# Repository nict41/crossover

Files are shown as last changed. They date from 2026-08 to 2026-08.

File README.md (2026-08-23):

# Variable Crossover — ESP Project 148

An EasyEDA-importable schematic for the **3-way state variable electronic
crossover** from Elliott Sound Products Project 148
(<https://sound-au.com/project148.htm>), redrawn from Figure 2.

Two cascaded 2nd-order state variable filters, 12 dB/octave, with continuously
variable crossover frequencies and adjustable Q. One channel — build two for
stereo.

Four variants are provided. They are the **same circuit** — identical filter
topology and identical signal connectivity, which the generator asserts on
every build — differing in the components that set the frequency range, in
whether the eight op-amp sections are packaged as four duals or two quads,
and in whether the board extras (volume controls, buffered outputs, muting)
are drawn:

| Variant | High/Mid | Mid/Low | Op-amps | File |
|---|---|---|---|---|
| Stock ESP P148 | 680 Hz – 4.8 kHz | 68 – 480 Hz | 4 × NE5532 dual | `esp-p148-3way-state-variable-crossover.json` |
| Retuned | 195 Hz – 1.03 kHz | 71 – 180 Hz | 4 × NE5532 dual | `esp-p148-3way-crossover-retuned-200hz-1khz.json` |
| Retuned, quad | 195 Hz – 1.03 kHz | 71 – 180 Hz | 2 × MC33079 quad | `esp-p148-3way-crossover-retuned-quad.json` |
| Retuned, quad, **SMD** | 195 Hz – 1.03 kHz | 73 – 186 Hz | 3 × MC33079 SOIC-14 | `esp-p148-3way-crossover-retuned-quad-smd.json` |

The **Retuned, quad** variant is electrically identical to the retuned one —
it just packs the same eight sections into two 14-pin quads instead of four
duals, which also halves the bypass caps (8 → 4). One quad per filter, so the
sections sharing a package are the ones already coupled by design.

The **SMD** variant is the one in `pcb/`, and it is not only a repackaging:
it adds a third quad (`U3`) for the output buffers, plus the volume controls,
the muting and the output DC blocking. That is why it lists three MC33079
where the through-hole quad variant lists two.

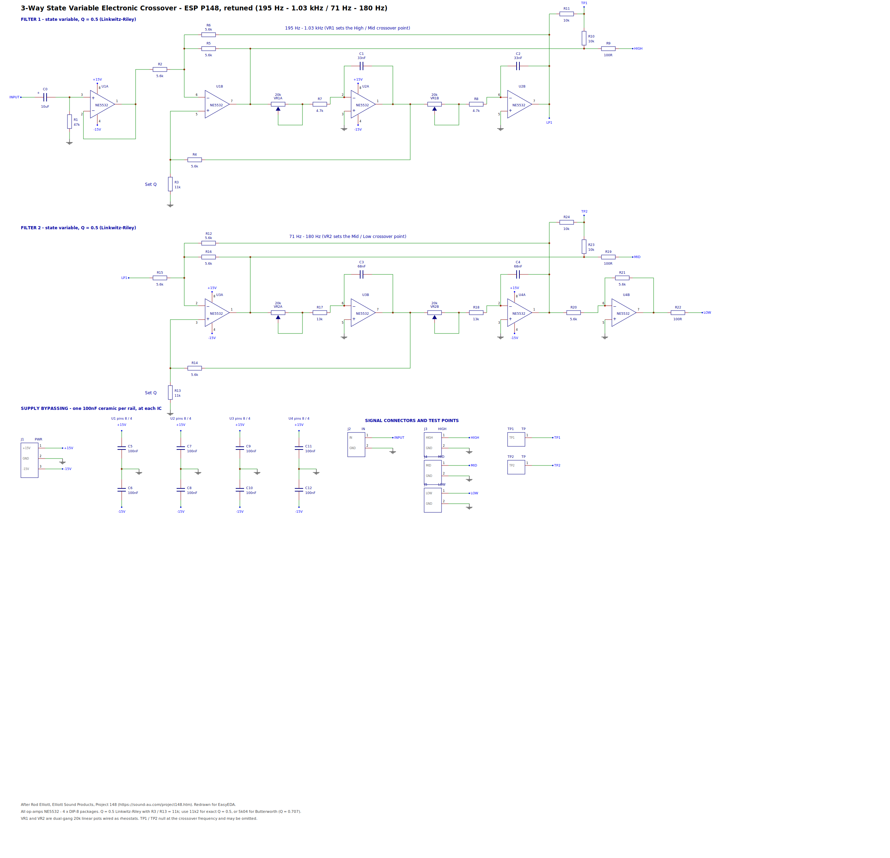
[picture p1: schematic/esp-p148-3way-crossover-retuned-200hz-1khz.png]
Schematic preview


## Importing into EasyEDA

Everything here targets **EasyEDA Standard** (<https://easyeda.com/editor>) —
the generated JSON is Std's `docType: 3` PCB / `docType: 1` schematic format.
EasyEDA Pro can read it via **File → Import → EasyEDA Std**.

### The PCB (the finished, routed board)

1. Open <https://easyeda.com/editor> and go to **File → Open → EasyEDA…**
2. Choose `pcb/esp-p148-3way-crossover-retuned-quad-smd-pcb.json`.

It opens as a complete **four-layer** board: routed, with a solid ground
plane on Inner1 and a ground pour on the other three, and real LCSC part
numbers already attached to every assembled component. Nothing needs
assigning before you can look at it or order it — but do rebuild the copper
areas first, for the reason in the next section.

### The schematic

Same menu, then a `.json` from `schematic/` — one per variant. If your
editor build rejects it, try the matching `.legacy.json`: identical
drawing, older string-form document header.

Schematic symbols carry **generic** package names (`R_AXIAL-0.4`, `DIP-8`,
…), so the schematic on its own is not ready for layout — but you do not
need it to be, because the PCB above is already laid out. The two are
separate documents rather than one linked project, so EasyEDA will not
cross-check them; `gen_pcb_smd.py` does that instead, and asserts the
board's pads match the schematic's pins exactly on every run.

### What to check once it is open

The generator verifies its own geometry and `tools/validate_fab.py` checks
the file against EasyEDA's format and JLCPCB's limits, but a few things can
only be confirmed by a real import:

1. **Rebuild the copper areas** (right-click a pour → *Rebuild copper
   area*, or **Tools → Rebuild all copper areas**). Ground is a **plane**
   on this board, not a routed net — Inner1 is a solid ground plane, the
   other three layers are poured, and only
   a handful of short stubs are drawn as traces. This used to be optional
   insurance; it is now the thing that connects ground, so do it before
   the DRC below or the DRC will tell you ground is unconnected.
2. **Does the silkscreen appear?** This is the one known unknown. Our
   `TEXT` shapes are written without the pre-rendered glyph path that
   EasyEDA's own exports carry, relying on the editor to re-render from the
   text and size. Normal for generated files, expected to work, unverified
   here. If the designators and pin labels are missing, that is why.
3. **Design → Design Rule Check**, with JLCPCB's rule set. It should be
   clean; the repo's own checker already requires ≥ 8 mil clearance against
   JLCPCB's 5 mil limit.
4. **Look at the 3D view / photo view.** Part orientation is the usual
   failure mode for a hand-drawn footprint, and the SOIC-14's pin-1
   rotation against JLCPCB's convention is explicitly unconfirmed (see
   "Known limitations").
5. **Export Gerbers, BOM and CPL from EasyEDA**, not from this repo — see
   "Ordering" in `docs/pcb-notes-smd.md` for why the CPL here is reference
   only.

## Before you build this

Read [`docs/design-review.md`](docs/design-review.md). It lists the failure
modes that pass every automated check, marks which of them the board now
fixes, and keeps the reasoning for the ones it does — including why turn-on
transients from an active crossover are a tweeter problem specifically
(fixed: JFET muting with soft start), and why per-band volume knobs with no
master is the wrong control architecture for a preamp (fixed: `VR6`). What
is left is mostly mechanical: unverified hand-drawn footprints, and the
fact that nothing here has been built and measured.

## Repository layout

```
schematic/   EasyEDA schematics (.json + .legacy.json), one pair per variant,
             each with a matching .svg / .png preview
pcb/         the routed SMD board (+ .svg / .png preview)
docs/        circuit-notes.md      — how the circuit works, design equations
             pcb-notes-smd.md      — the board: layout, routing, verification
             design-review.md      — what could still go wrong
             panel-drilling.md     — GENERATED: front-panel hole positions
             parts.md              — GENERATED: the BOM, plus what you solder
             task-board.md         — open work, and what serialises
             decisions.md          — append-only log of what was measured
             subcircuits/          — GENERATED: one diagram per function block
             crossover-ranges.svg  — tuning-range diagram (+ .png)
             netlist.txt           — netlist extracted back out of the drawing
bom/         one bom-*.csv per variant, plus the JLCPCB BOM and CPL
tools/       gen_schematic.py     — generates the schematics
             gen_pcb_smd.py       — SMD PCB, routed + verified
             gen_range_diagram.py — generates the range diagram
             validate_fab.py      — EasyEDA import + JLCPCB limit checks
             find_board.py        — searches seeds/route orders for a clean board
             gen_spice.py         — SPICE deck, from the same netlist as the board
             run_sim.py           — runs the circuit-verification suite
             place.py / anneal.c / canneal.py   — the placement anneal
             router.c / croute.py               — the grid maze router
             geom.c  / cgeom.py                 — the exact-geometry checks
sim/         GENERATED: the ngspice deck (crossover.net, models.lib,
             jfet-*.lib). Analysis decks and their results are not committed.
```

`place.py`, `router.c` and `geom.c` each have a Python reference
implementation beside the compiled one (`PLACER=py`, `ROUTER=py`,
`CGEOM=py`), so every compiled path can be checked against readable code.

## Contributing (human or agent)

[`AGENTS.md`](AGENTS.md) is the one-page contract — it matters here more
than in most repositories, because almost everything in `schematic/`,
`pcb/`, `bom/`, `sim/` and several files in `docs/` is **generated**, and
editing the output instead of the generator is silently discarded.

```sh
python3 tools/check_all.py     # the gate: regenerate, verify, validate
```

Open work is in [`docs/task-board.md`](docs/task-board.md), marked by
whether it forces a board re-search (and so can only be done one at a
time). Measurements — kept *and* rejected — go in
[`docs/decisions.md`](docs/decisions.md).

## Regenerating

The schematic is generated, not hand-edited, so that the drawing and the netlist
can't drift apart:

```sh
python3 tools/gen_schematic.py      # schematics, previews, netlists, BOMs
python3 tools/gen_pcb_smd.py        # SMD board (routed; needs numpy)
python3 tools/gen_range_diagram.py  # docs/crossover-ranges.svg + .png
python3 tools/validate_fab.py --online   # EasyEDA import + JLCPCB limits
python3 tools/gen_spice.py && python3 tools/run_sim.py   # circuit simulation
```

`gen_spice.py` builds the ngspice deck from the **same netlist JSON the
board is built from**, so the thing that gets simulated cannot drift from
the thing that gets manufactured. `run_sim.py` then measures the crossover
points, the summed response, the DC at each output terminal, and the mute
chain. It needs `ngspice` (`apt install ngspice`).

`gen_pcb_smd.py` reads the netlist JSON that `gen_schematic.py` writes, so the
board cannot drift from the schematic — run them in that order.

Both need `cairosvg` for PNG output (`pip install cairosvg`); the SVGs are
written regardless.

The script places every component and wire on a 10 px grid, derives junction
dots from wire degree, then **re-extracts the netlist from the finished
geometry** and prints it. That extracted netlist is what's in `docs/netlist.txt`
— it is a check on the drawing, not a restatement of intent.

It builds every entry in `VARIANTS` and asserts that they all produce the same
netlist, so a retune that accidentally changed a connection would fail the
build rather than ship quietly.

## Circuit summary

Designators below are the **four-dual** drawing's. On the quad variants —
including the board — the same eight sections are U1A–D and U2A–D; that
mapping, and every part the board adds beyond the filter, is in
[`docs/circuit-notes.md`](docs/circuit-notes.md#function-blocks-on-the-smd-board).

| | Filter 1 | Filter 2 |
|---|---|---|
| Summing amp (high-pass out) | U1B → **HIGH** | U3A → **MID** |
| Integrator 1 (bandpass, feedback only) | U2A | U3B |
| Integrator 2 (low-pass out) | U2B → filter 2 | U4A → U4B → **LOW** |
| Frequency pot | VR1 (dual 20k) | VR2 (dual 20k) |
| Integrator caps | C1, C2 | C3, C4 |
| Q resistor | R3 = 12k | R13 = 12k |

Q = (5.6k + Rq) / (3 × Rq): 11k2 gives exactly 0.5 (Linkwitz-Riley), 11k gives
0.503, 12k gives 0.489, 5k04 gives Butterworth (Q = 0.707, 3 dB peak in the
summed response). The stock variant keeps the published 12k; the retuned
variant uses 11k, which is a stock value and four times closer to ideal.

The inverter U4B sits on the **bass** output rather than the midrange because
U3A, the input amplifier of the second filter, is already inverting.

TP1 and TP2 sum each filter's high-pass and low-pass outputs through 10 k
resistors; the signal nulls at the crossover frequency, so you can measure it
exactly with an oscillator. They're optional — the ESP PCB omits them.

### Tuning ranges

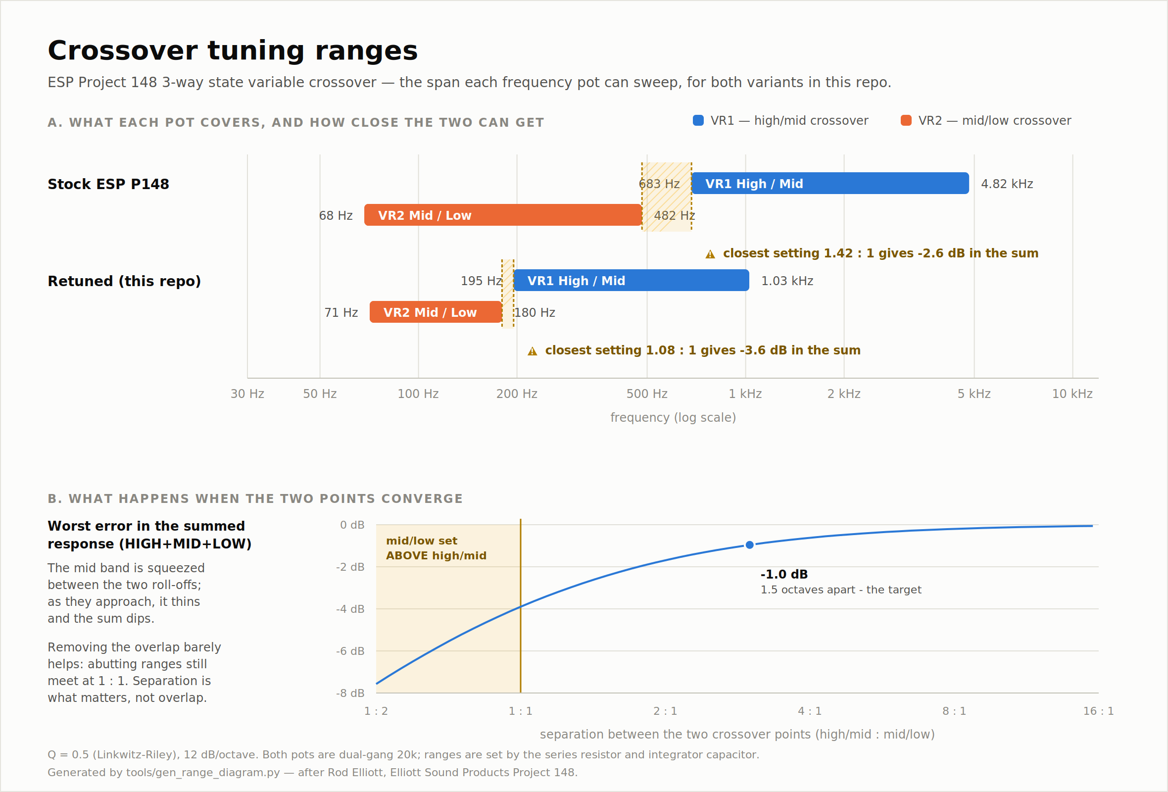
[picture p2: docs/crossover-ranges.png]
Crossover tuning ranges


The retuned ranges don't overlap, but that is **not** what keeps the response
flat — separation is. Because the two filters are tuned independently, nothing
stops you setting them close together, and ranges that merely abut still meet
at the boundary:

| Range layout | Closest possible setting | Sum error there |
|---|---|---|
| Stock ESP P148 | 1.42 : 1 | −2.62 dB |
| Retuned | 1.08 : 1 | −3.57 dB |

The outputs never swap — filter 1 is unaware of filter 2, so HIGH is
unaffected. What collapses is MID, whose passband *is* the gap between the two
corners: squeeze that gap and it thins out, and the summed response develops a
broad suck-out. The degradation is gradual and already measurable at 1.6 : 1,
so the rule is **keep the two points at least 3 : 1 apart** (~1.5 octaves) for
under 1 dB. That's setting discipline, not something the hardware enforces —
note the stock ESP values have the same exposure. Nothing is damaged or
unstable; turn VR2 back down and it recovers. Full detail in
[`docs/circuit-notes.md`](docs/circuit-notes.md#setting-the-two-points-too-close-together).

### Frequency range

`f = 1/(2πRC)`, where R sweeps from the series resistor alone to series + 20 k
pot. The series resistor therefore sets both the top frequency *and* the
max/min ratio:

| Variant | R7, R8 | C1, C2 | High/Mid | R17, R18 | C3, C4 | Mid/Low |
|---|---|---|---|---|---|---|
| Stock | 3.3k | 10 nF | 683 Hz – 4.82 kHz | 3.3k | 100 nF | 68.3 – 482 Hz |
| Retuned | 4.7k | 33 nF | 195 Hz – 1.03 kHz | 13k | 68 nF | 70.9 – 180 Hz |

Nothing else differs — same Q, same op-amps, same 20 k pots. Larger series
resistors also load the previous stage *less*, so this direction is safe; the
article only warns against going below ~2.2k.

Full explanation, design equations and frequency tables: [`docs/circuit-notes.md`](docs/circuit-notes.md).

## Subcircuits

One diagram per functional block of the board, in
**[docs/subcircuits/](docs/subcircuits/README.md)**: input and master volume,
each of the two crossover filters, the level controls, the output buffers, the
two halves of the muting circuit, and power/decoupling.

They are **generated, not drawn**. `tools/gen_schematic.py` crops each block
out of the full sheet through the same `render_svg()` that renders the main
schematic, so the symbols, strokes and fonts are identical to it and cannot
drift. Rebuild them with:

```bash
python3 tools/gen_schematic.py
```

The part-by-part tables that go with the pictures are in
[docs/circuit-notes.md](docs/circuit-notes.md#function-blocks-on-the-smd-board).

## Additions to the original drawing

The ESP figures deliberately leave out supply wiring. This schematic adds it so
the netlist is complete:

* **J1** — ±15 V and ground input.
* **C5–C10** — 100 nF ceramic from each op-amp package's positive and negative
  supply pin to ground, as the article's text requires. Mount them right at
  the ICs; the board's placement search prices the distance directly.
* **C11, C12** — 10 µF bulk reservoir, one per rail.
* **R10/R11** and **R23/R24** — the unlabelled 10 k test-point resistors in
  Figure 2, given designators.

The `retuned-quad-smd` variant — the one the board is built from — adds more
still: a master volume, per-band volume trims, buffered outputs with DC
blocking and bleeders, and per-output muting with soft start. Every part and
what it does is listed in
[`docs/circuit-notes.md`](docs/circuit-notes.md#function-blocks-on-the-smd-board).

## Known limitations

### Of the schematics

These apply to the four `schematic/` variants. **None of them applies to the
routed board** — it has real footprints, real LCSC part numbers and a
verified layout; see the next list for its limitations.

* **Op-amps are drawn as separate sections** (U1A/U1B, U2A/U2B, …) rather than
  as multi-part components, so the BOM lists eight NE5532s where you only need
  four dual packages. Before PCB layout, merge each pair onto one DIP-8/SOIC-8
  part in EasyEDA. Supply pins 8 and 4 appear on the A section of each package
  only, which is the usual convention.
* **VR1 and VR2 are two dual-gang 20 k pots**, drawn as four gangs (VR1A, VR1B,
  VR2A, VR2B). Both gangs of a pot must track reasonably well.
* **VR3–VR6 are single-gang audio-taper pots** — three band trims and a
  master. They are passive attenuators, not part of any filter.
* **Footprints are placeholders** in the schematics. Assign real ones from the
  EasyEDA/LCSC library for your parts (axial vs. 0805, pot body, etc.).
* One deliberate wire crossing per filter, where the low-pass feedback rail
  crosses the high-pass rail. Crossings without a junction dot do not connect.

### Of the routed board

* **Nothing here has been built or measured.** It is verified against its own
  netlist, its own geometry, and — since the simulation work — its own
  behaviour in ngspice. All three are different claims from "it works on a
  bench".
* **The simulation cannot predict THD.** The op-amp is a behavioural
  macromodel with no device-level nonlinearity, so the distortion floor it
  reports is a measurement artefact. It is good for topology questions —
  does a device conduct when it should not, where do the crossover points
  land, what DC reaches the output — and useless for a distortion figure.
* **Winding both frequency knobs together collapses the mid band.** The
  two ranges deliberately do not overlap (73–186 Hz and 195 Hz–1.03 kHz),
  but they are *adjacent*: set both to the near end and the mid band is
  9 Hz wide, peaks 11.7 dB down, and the summed response has a 3.6 dB
  hole. Nothing prevents it and nothing on the panel warns about it —
  keep the two knobs apart.
* **Three footprints are hand-drawn and unconfirmed against a datasheet** —
  SOIC-14, the 10 µF electrolytic, and the dual-gang pot body. The pot's
  locating-boss holes are absent rather than guessed: a hole in the wrong
  place is a re-order, a missing one is a hand drill.
* **Whether the silkscreen renders after import is untested.** Our `TEXT`
  shapes carry no pre-rendered glyph path, which is normal for generated
  files and expected to work — but it is the one thing that cannot be
  checked without importing.
* **The board is past JLCPCB's 100 × 100 mm price tier** at 149.6 mm on its
  long side. That is set by the nine front-panel controls, not by routing:
  a control costs panel width whatever the router does.

## KiCad

`kicad/esp-p148-3way-crossover-retuned-quad-smd.kicad_sch` — the same
schematic as a **KiCad 8 schematic**, generated by `tools/gen_kicad.py`.
Open `kicad/crossover.kicad_pro`, or the `.kicad_sch` on its own.

It is **self-contained**: every symbol is embedded in the file's own
`lib_symbols`, one per component instance, so nothing needs to be
installed and no library path has to resolve. Nets are carried by labels
exactly as they are drawn.

It is not a second drawing of the circuit. `gen_kicad.py` reads the very
geometry `gen_schematic.py` lays out — every pin in absolute coordinates,
every wire polyline, every label — and translates it, so the two cannot
disagree about connectivity. And it checks: after emitting the file it
parses it back, rebuilds the netlist from the geometry alone, and refuses
to write anything unless that matches the schematic's own netlist.

`kicad/esp-p148-3way-crossover-retuned-quad-smd.kicad_pcb` — a **routing
seed**, for handing to an external router or placement tool. It is placed
but not wired:

* the committed outline at its real size, **149.6 × 63.5 mm**;
* the **edge components on the board** at their committed positions — the
  nine front-panel controls and the five rear connectors — because those
  are mechanical and not a router's to move;
* **every other part parked outside the outline** on a grid, to be placed;
* the full netlist on the pads, so there is a ratsnest to work from;
* the four mounting holes, so nothing routes through a screw;
* and **no tracks, no vias and no zones** — not even the ground pour this
  project otherwise treats as load-bearing.

It is read from the committed `pcb/*.json`, so it cannot describe a board
that was never built, and the emitted file is parsed back and checked
before it is written: bare of copper, every edge part inside the outline,
every other part clear of it, pad nets identical to the board's.

## PCB

### SMD board, routed, for JLCPCB fab + assembly

`pcb/esp-p148-3way-crossover-retuned-quad-smd-pcb.json` — **149.6 ×
63.5 mm**, **four layers**, **fully routed**, nine front-panel controls on
the board (a frequency pot and a volume trim per band, a master volume, and
a mute button per band), trace width matched to purpose (12 mil signal,
16 mil power/ground), 45° chamfered corners, every SMD part a real LCSC
line item.

The stackup is L1 signal / **L2 solid GND plane** / L3 signal / L4 signal.
Two layers could not route this board once the three panel mute buttons
went into the front row — see
[`docs/pcb-notes-smd.md`](docs/pcb-notes-smd.md#the-stackup).

Every part that reaches an edge is pinned into one of two rows — the panel
row on the front, the connector row on the back — and nothing may sit
outside either, so the board edges land 1.27 mm behind them. See
[Two pinned edge rows](docs/pcb-notes-smd.md#two-pinned-edge-rows).

Every SMD ground pad is **fanned out to the plane before any signal net is
routed** — a via on the pad, straight down. Repairing ground afterwards
does not work once the traces are down, and that is what used to leave
op-amp ground pins stranded.

Beyond the filter itself it carries buffered outputs with build-out
resistors, DC blocking and bleeders, a 47 kΩ line input, bulk and per-IC
supply decoupling, and **per-output muting with power-up soft start** — a
JFET shunting each buffer input, steering diodes so one button mutes one
band, and an RC that holds everything muted until the rails settle and
re-mutes fast when they collapse. The three mute buttons are **on the
board**, in the panel row beside the volume trims - right-angle push-lock
DPDTs, so their plungers come out of the board edge alongside the pot
shafts. `J6` carries only the optional panel LEDs, which light when a band
is playing. No audio leaves the board. Which parts do what, block
by block, is in
[`docs/circuit-notes.md`](docs/circuit-notes.md#function-blocks-on-the-smd-board).

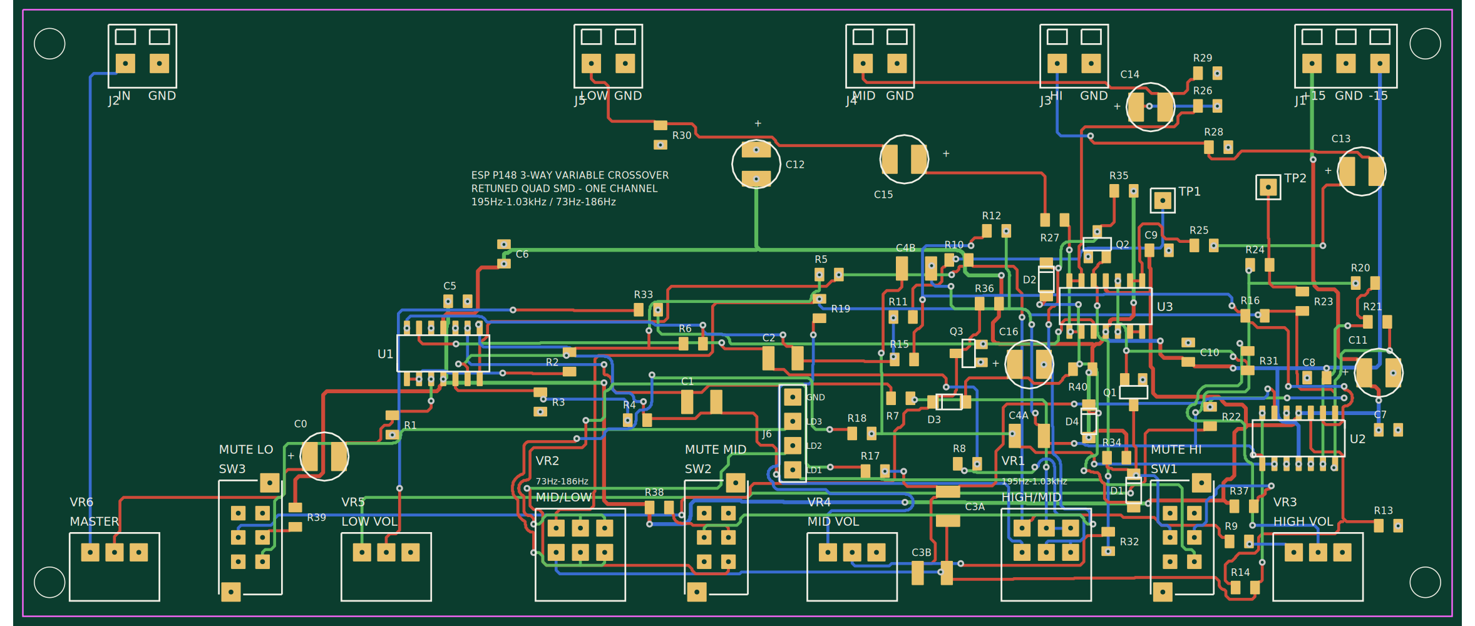
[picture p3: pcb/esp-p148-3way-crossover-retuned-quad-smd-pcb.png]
SMD board


```
board 149.6 x 63.5 mm | 86 footprints | 242 pads | 227 tracks | 159 vias
verified: all nets connected, all clearances >= 8 mil, no unrouted nets,
          pads match the schematic exactly
```

On the rear edge, left to right: **line input, LOW, MID, HIGH, power** —
the three outputs adjacent and in the same order as the front panel, with
the power block at the far end from the input so the two looms never run
together. On the front edge, left to right: MASTER,
**LOW mute**, LOW volume, MID/LOW frequency, **MID mute**, MID volume,
HIGH/MID frequency, **HIGH mute**, HIGH volume — nine controls, each mute
button beside the volume trim it mutes. The board lies **flat in the
enclosure, perpendicular to the front panel**, with right-angle pots and
right-angle switches on the front edge and their shafts and plungers
through the panel — the way a small amplifier board is usually arranged.
The frequency pots carry their sweep range on the silkscreen. The volume controls are single-gang
audio-taper pots (Alps RK097 pattern) wired as attenuators; the frequency
pots are the standard 9 mm dual-gang pattern. Both **need checking against
your parts' datasheets** — there are no locating-boss holes, deliberately;
see the notes.

**Drilling the panel:** [`docs/panel-drilling.md`](docs/panel-drilling.md)
is generated from the same placement as the copper, and gives the X of every
shaft and plunger from the board's left edge, the two pitches the row uses,
and where the four mounting holes actually ended up. Regenerate the board
and that file follows it, so it cannot drift from the part positions the way
a measured-off-the-preview drawing would.

Routing is checked by geometry that doesn't reuse the router's own bookkeeping:
exact pairwise clearance between every copper feature, union-find connectivity
per net, mounting-hole keepout, footprint-courtyard overlap, and pad-set
equality with the schematic. Those checks have caught real defects that would
otherwise have reached the fab, including a pre-existing footprint overlap
between two adjacent parts that nothing before the courtyard check could even
detect — see [`docs/pcb-notes-smd.md`](docs/pcb-notes-smd.md).

Part numbers were looked up live against the JLCPCB parts API; **re-check stock
before ordering**. Export Gerbers, BOM *and* CPL from EasyEDA rather than using
the CPL in this repo — a CPL's origin has to match the Gerbers, and only EasyEDA
knows that at export time.

JLCPCB won't assemble through-hole parts. **69 of the 86 footprints are
machine-placed**; the 17 you solder yourself are all through-hole and all of
them are edge or panel hardware:

* `VR1`–`VR6` — the six pots
* `SW1`–`SW3` — the three mute buttons
* `J1`–`J5` — power in, line in, and the three outputs
* `J6` — the optional panel-LED header
* `TP1`, `TP2` — the two test points

There is no off-board pot or switch wiring any more: every control is an
edge-mount part on the board itself.

## Getting the most out of it

The circuit is already lean, so build effort is easy to spend in the wrong
place. In order of what actually measures:

1. **Match within each filter.** The two integrator caps (C1/C2, C3/C4) and the
   two series resistors need to match *each other* — absolute value only sets
   the range. A mismatch acts exactly like pot mistracking, moving f0 and Q by
   its square root: 10 % costs −0.41 dB, 20 % costs −0.79 dB. Use 1 % resistors
   and matched caps; 5 % is fine everywhere else.
2. **Buy pot tracking, not exotic op-amps.** Same maths applies to the two
   gangs. And don't fit log-taper pots for a more even frequency scale — their
   gang tracking is much worse, and it lands straight on Q.
3. **Q resistor 11k, not 12k** — already done in the retuned variant. Free.
4. **Two quads instead of four duals** — shipped as the `retuned-quad`
   variant. The circuit splits perfectly at the filter boundary, four sections
   each, so one quad per filter: half the ICs, half the bypass caps, smaller
   board, no circuit change. Drawn with the MC33079 (closest in character to
   the NE5532); any standard quad pinout drops in — OPA1644, OPA4134,
   LME49740, TL074.

Things that look like simplifications but aren't: the input buffer U1A keeps
source impedance out of the Q and gain; the integrators have no DC feedback of
their own, so the state-variable loop must stay intact. Detail in
[`docs/circuit-notes.md`](docs/circuit-notes.md#where-accuracy-actually-pays).

## Building notes

* NE5532 is what the article specifies, for noise. Any decent audio dual op-amp
  will work.
* The 5.6 k resistors were 10 k in earlier versions of the article; 5.6 k was
  chosen to reduce thermal noise. Anything up to 10 k is fine, above that isn't
  recommended.
* To move a frequency range, change the integrator capacitors — smaller caps
  give a higher range. 4.7 nF in filter 1 gives roughly 1.45 kHz – 10 kHz.
  Watch that a test tweeter isn't driven below its rated minimum frequency.

## Credit and licence

Circuit design © Rod Elliott, Elliott Sound Products, Project 148 (2014).
The ESP article grants personal use and one printed copy for reference while
building; commercial use needs Rod Elliott's written permission. This repository
holds a re-drawn schematic for personal construction — please read the article
itself, and buy the ESP PCB if you want one.

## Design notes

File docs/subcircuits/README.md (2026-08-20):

# Subcircuit diagrams

One diagram per functional block of the SMD board. They are **generated**,
not drawn: `tools/gen_schematic.py` crops each block out of the full sheet
through the same `render_svg()` the main schematic uses, so the symbols,
strokes and fonts are identical and cannot drift from it. Re-run
`python3 tools/gen_schematic.py` to rebuild them.

The part-by-part tables for each block are in
[`../circuit-notes.md`](../circuit-notes.md#function-blocks-on-the-smd-board);
these are the pictures.

## Input and master volume

The line input, the master volume ahead of everything, and the unity-gain buffer that drives the first filter.

Input and master volume

## Crossover filter 1 - the HIGH / MID split

State-variable filter. `U1B`'s output IS the high-pass; `U1D`'s is the low-pass that feeds filter 2. `VR1` sets the split frequency.

Crossover filter 1 - the HIGH / MID split

## Crossover filter 2 - the MID / LOW split

The same topology again on filter 1's low-pass output, splitting it into MID and LOW. `U2D` inverts the bass output.

Crossover filter 2 - the MID / LOW split

## Level controls

Master volume plus one trim per band, all passive attenuators after the filter and before the buffer.

Level controls

## Output buffers and DC blocking

One unity-gain buffer per band, a build-out resistor, a DC blocking cap and a bleeder, into a terminal block with its own ground return.

Output buffers and DC blocking

## Muting - the shunt devices in the signal path

`Q1`-`Q3` shunt each buffer input to ground through `R31`-`R33`. Drawn here rather than with the rest of the mute circuit because this is where they sit electrically: across the buffer input.

Muting - the shunt devices in the signal path

## Muting - gate control, buttons and soft start

The gate pulldowns that unmute, the steering diodes that keep one button from muting all three bands, the `R40`/`C16` soft start that holds everything muted until the rails settle, and `SW1`-`SW3` themselves - the on-board latching buttons, one pole grounding the gate line and the other switching that band's LED feed out to `J6`.

Muting - gate control, buttons and soft start

## Power and decoupling

The supply terminal block, the bulk reservoir per rail, and a 100 nF bypass on each rail at each IC.

Power and decoupling

---

Free-standing text is left out of the crops on purpose. Section headings and
the sheet notes sit near a block but belong to no part, so a crop cannot
attribute them - and an adjacent block's heading landing on this diagram
would caption it with the wrong name.

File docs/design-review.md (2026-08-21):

# Design review — what could go wrong, in the fab and in use

Written by working through the board and the circuit looking for failure
modes, not by running the checkers. Everything the checkers cover is
already covered; this is the set of problems that pass every automated
test and still bite you.

Ordered by **what it costs you if it happens**, not by how likely it is.

---

## 1. Bypass capacitors are 37–63 mm from the pins they decouple

**Severity: high. Status: FIXED.** Now 4.2–10.0 mm, against the
hand-placed through-hole board's 11 mm. Kept here because the *reason* it
happened is the durable lesson, and because it took a 24x speedup to make
the fix affordable.

`C5`–`C8` are the 100 nF supply bypasses, one per rail per op-amp. They
are 37, 38, 40 and 63 mm from the supply pins they belong to. A bypass
cap's entire job is to supply transient current through as little loop
inductance as possible; a centimetre of trace is already about 10 nH, so
at 60 mm the capacitor is decoupling nothing that matters. The op-amps are
effectively running with no local supply bypassing at all.

**Why it happened, and why no check caught it.** The placement search
optimises courtyard overlap, pin escape, congestion, wirelength and board
size. A bypass cap is invisible to every one of those: it is two pads on
`+15V`/`-15V` and `GND`, nets which already span the whole board, so
moving it barely changes any half-perimeter, and it is far too small for
area or congestion to notice. Nothing was broken — the optimiser did
exactly what it was told, and nobody had told it about decoupling. The
*hand-placed* through-hole board gets this right at 11 mm, by eye.

**How it was fixed, and why that took two attempts.** The placement search
gains a pin-to-pin proximity term (`BYPASS_NEAR`). On the first attempt it
produced a correct placement that **would not route** — 0 clean boards out
of 208 seed and route-order combinations, and 0 of 40 more after
slackening size pressure to give the router room, which made things
*worse* because a bigger board means longer nets.

That was a budget problem disguised as an engineering one. Each attempt
cost ~30 s, almost all of it in the Python placement anneal, so 208
attempts was as far as the budget stretched. Compiling the anneal took a
trial to ~2.5 s; the next search found a clean board in 80 trials. The
constraint had been right all along and the search had simply been too
expensive to run far enough.

---

## 2. Turn-on and turn-off thumps go straight to your tweeters

**Severity: high, for this specific application. Status: FIXED on the
board.** Every output now has a JFET mute (`Q1`-`Q3`) with a power-up soft
start (`R40`/`C16`, ~2 s) and a fast re-mute as the rails collapse (`D4`),
plus 10 µF DC blocking (`C13`-`C15`) and bleeders (`R28`-`R30`). See
[`circuit-notes.md`](circuit-notes.md#muting-and-soft-start). The text
below is what the board looked like before, and why it mattered.

Every output was DC-coupled — op-amp, 100 Ω series resistor, volume pot,
terminal block — with no muting, no output relay and no power-up
delay. When the ±15 V supply comes up, the filter sections settle through
whatever transient their RC networks dictate, and that transient appears
at all three outputs at once.

An active crossover is worse than a normal preamp here, because **the HIGH
output feeds the amplifier driving your tweeters**. A tweeter has no
mechanical or thermal headroom for a large step, and it is the driver
least able to survive one.

It is also asymmetric in a way that catches people out: supply *collapse*
at switch-off is usually messier than switch-on, because the two rails
rarely decay together.

**What a blocking capacitor would and would not do.** The output DC
blocking caps under §3 are now fitted, and they do not stop a thump — the
transient edge passes straight through them — they only stop the
*sustained* offset that follows one. Muting is the fix for thumps; a
capacitor is the fix for faults. Do not read §3 being fixed as this one
being fixed.

**What it deliberately does not do.** A muting relay wants a relay, a
timing circuit, a flyback diode and a transistor per channel, and it needs
to hold the mute until the rails are *stable*, which means sensing them.
That is a power-supply-side function, not a filter-side one, and putting it
here would roughly double the part count of a board already at the limit of
what its router can place. It belongs on the PSU board or as a dedicated
module — ESP's P33 is exactly this, and any "speaker protection / soft
start" module does the job.

**If you build nothing extra:** power the crossover up *before* the
amplifiers and down *after* them. A switched outlet strip enforces it; so
does habit, until the one time it doesn't.

---

## 3. A single op-amp failure puts DC into your power amplifiers

**Severity: high impact, low probability. Status: FIXED and shipped.**

There was no DC blocking on the outputs. If an op-amp section failed with
its output stuck at a rail, up to about 14 V DC reached the volume pot and
the wiper delivered a fraction of that to the amplifier input — which a
DC-coupled power amplifier would faithfully amplify until the speaker gave
up.

`C11`–`C13` are 10 µF in series with each output, on the wiper side of the
attenuator. Into a 10 kΩ amplifier input that puts the corner near 1.3 Hz,
far below anything the LOW band carries. They are on by default; set
`OUTPUT_CAPS=0` to build without them.

**Why this was blocked for so long, and what actually unblocked it.** For
several rounds these caps were written and switched off, because the board
would not route with them. Measured, with the placement search made
deterministic first:

| footprints | what | clean boards |
|---|---|---|
| 49 | as shipped then | 1 in 80 |
| 52 | + output blocking caps | **0 in 320** |
| 54 | + bulk decoupling as well | **0 in 320** |
| 52 | output caps shrunk to 1210 ceramic (⅓ the area) | **0 in 160** |

The last row is the one that mattered: making the parts three times
smaller changed nothing, so it was never the area they occupied. Two other
things were tried and are worth not repeating — putting the caps *between*
the filter and the pot (electrically better, since it also keeps DC off
the pot track) splits the `*_PRE` nets, which already cross most of the
board, and made it strictly worse; and giving the board more room made it
worse again, for the reason this repo keeps rediscovering.

The fix was not in the router at all. **Ground stopped being routed.** The
board has always carried a GND pour on every signal layer, but nothing
verified it, so ground was *also* drawn as an ordinary net — the largest net on the
board, and `route_order()` sends supply rails first, so it claimed the
best channels before a single signal net got a turn. The board was paying
for ground twice and spending its best routing resource on the payment.

`pour_connectivity()` now proves the plane is one piece of copper that
reaches every ground pad, modelled conservatively from the router's own
occupancy and eroded to the pour's minimum width so a hairline neck cannot
count as a connection. That check is what makes leaning on the plane safe.
GND is then routed only where the pour genuinely cannot squeeze in — a
handful of short stubs into the plane, instead of a tree spanning the
board. With the channels that freed up, 54 footprints route clean, and
both this fix and §5 are in the shipped board.

The general lesson is worth more than the fix: **when adding a correct
circuit change is repeatedly impossible, suspect what the board is already
spending its resources on, not the size of the thing you are adding.**

---

## 4. Using this as a preamp means three volume knobs and no master

**Severity: high usability. Status: FIXED.** `VR6` is a 50 kΩ audio-taper
master, sitting ahead of the input buffer so it sets listening level
without touching the crossover balance; the three band pots became trims.
The reasoning below is why that was the right place to put it.

The three volume pots are per-band level controls. There was no master
volume. To change listening level you have to move three knobs together
and match them, which is not practical to do accurately by ear or by eye —
and any mismatch is a change in crossover balance, not just level.

In stereo it is worse: two boards, **six** single-gang pots, with no
mechanical tracking between left and right. Pot tolerance alone
(typically ±20 %) means the two channels will not match at the same knob
angle.

**The conventional architecture** is a single dual-gang master volume
*ahead* of the crossover input, with the per-band pots set once as trims
and then left alone. That is one knob for listening level, correct stereo
tracking, and the band trims doing the job they are actually good at.

**This cannot be fixed on this board, and that is not a cop-out.** The
board is one channel. A master volume for a stereo pair has to be one
dual-gang pot feeding *both* boards, so it is inherently off-board — put it
between your source and the two `J2` inputs. Anything fitted per-board
would be one gang per channel and would not track, which is the problem
you started with.

Note the taper interacts with this: the fitted pots are **audio (log)**
taper, which is right for a control you sweep to silence and wrong for a
trim you nudge around 0 to −12 dB, where linear gives you far more useful
rotation. If you adopt a master volume, the band pots would be better as
linear.

**The loading objection is gone.** This used to end with a warning: the
board's input impedance was 10 kΩ (`R1`), so a 10 kΩ master pot feeding it
would be loaded hard enough to distort its taper badly, and you had to put
a buffer in between or raise `R1`. `R1` is now **47 kΩ**, the ordinary
line-level figure, so a 10 kΩ dual-gang master pot straight into both
channels' `J2` is fine — the worst-case wiper impedance of 2.5 kΩ into
47 kΩ is about 0.45 dB of error at one point on the travel.

10 kΩ was never a line input; it was a power-amp input, and it also loaded
a passive source or a valve output stage hard enough to lose level and
bass. Raising it costs bias-current offset — 300 nA of MC33079 input
current through 47 kΩ is 14 mV at the buffer output — and that is only
acceptable because §3's blocking capacitors now stop it reaching an
amplifier. At DC the high-pass outputs have no gain, so it only actually
appears at `LOW`. A FET-input op-amp (`OPA1644`, `OPA4134`, `TL074`)
removes it entirely.

---

## 5. No bulk supply decoupling on the board

**Severity: moderate. Status: FIXED and shipped.**

The board's entire supply decoupling was 4 × 100 nF. The ±15 V arrives
over an umbilical from an off-board supply, and wiring runs about 1 µH per
metre; that inductance and the ceramics alone form a high-Q resonance in
the low hundreds of kHz, exactly where an op-amp's supply rejection has
fallen away.

`C9`/`C10` add 10 µF per rail at the connector. That is on the small
side — 47–100 µF is the textbook figure — and the value was chosen to
reuse the 10 µF part already on the board rather than add a BOM line and a
second electrolytic footprint. It moves the resonance down by a factor of
ten and damps it with the electrolytic's own ESR, which is most of the
benefit. On by default; `BULK_CAPS=0` builds without them.

Same history as §3: correct from the day it was written, unfittable until
ground stopped being routed as a net. See §3 for why.

**Put the larger bulk capacitance at the supply end**, where it belongs
and where there is room for it. Decoupling an umbilical wants capacitance
at *both* ends; this board now holds up its end.

---

## 6. Reverse-polarity or mis-wired supply destroys both op-amps

**Severity: moderate. Status: not fixed, deliberately.**

`J1` is a 3-way screw terminal, `+15 / GND / −15`. Swap the outer two and
both MC33079s are reverse-biased. There is no series protection diode, no
fuse, and no keying beyond the silkscreen.

`GND` in the middle is a good choice — the most likely single-wire error
is harmless. Two-wire transposition is not.

Series protection diodes were considered and left out. They would need a
new footprint class and two more parts on a board whose router is already
the binding constraint, they cost about 0.5 V of rail each (Schottky), and
they protect against a mistake that a **polarised connector on the loom
prevents outright, for nothing**. If you are making the umbilical yourself,
key it. If you want the belt as well as the braces, `SS14` in SMA is the
part (LCSC `C55127344`), one in each rail, cathode toward the board on
+15 V and anode toward the board on −15 V.

---

## 7. Output impedance is set by the volume pot, not the op-amp

**Severity: low. Status: FIXED.**

The op-amp used to drive through a 100 Ω build-out resistor into the top of
a 10 kΩ pot, with the **wiper** feeding the terminal block, so the source
impedance peaked around 2.5 kΩ at mid-rotation rather than the few
milliohms an op-amp output gives.

Two things followed from that, and the second is the one that actually
mattered. Cable capacitance rolled off the top end — about 200 kHz with 3 m
of typical cable, which is fine. But a low-impedance amplifier input sat
across the lower half of the pot track, so it both lost level (about 1.9 dB
into 10 kΩ) and **changed the taper by an amount that depended on which
amplifier was plugged in**. Tolerable for a crossover fed from a preamp;
wrong for something used *as* one.

`U3` is a third quad op-amp: one unity-gain follower per band, between the
wiper and the terminal block. The output impedance is now the op-amp's, the
pot is unloaded so its taper is the taper it was bought with, and 2.5 kΩ of
source impedance is no longer sitting on a cable run picking up hum.
`R25`–`R27` are the buffers' build-out resistors; `R9`/`R19`/`R22` stay
where they were, doing the same job for the filter op-amp that drives the
pot. `U3D` is the spare section, input grounded and output tied back —
an unused op-amp section left floating oscillates and couples that into
the three sharing its supply pins.

Order along the chain is deliberate: pot, buffer, build-out, **blocking
capacitor**, terminal. The capacitor stays last so it still blocks a
failure of the last active device in the path. Ahead of the buffer it
would keep DC off the pot track — worth something, since DC through a
wiper is what makes a volume control crackle as it wears — at the cost of
leaving a failed `U3` section wired straight to a power amplifier, which is
worth much more.

`R28`–`R30` (100 kΩ, output to ground, after the capacitor) are the other
half of this. The coupling capacitor's outer plate otherwise has a DC path
only through whatever is plugged into the terminal block, so a board left
with nothing connected drifts on leakage and thumps into the amplifier the
moment one is connected.

**Use screened cable to the amplifiers** anyway. It is no longer needed to
keep hum out of a 2.5 kΩ source, but it is still an unbalanced line-level
interconnect.

---

## 8. The mute JFET stops being off before the circuit runs out of headroom

**Severity: high. Status: FIXED, by a part change that costs no layout.**

`Q1`-`Q3` shunt each buffer input to ground. When a band is unmuted the
gate sits at the −15 V rail and the drain carries the signal, so a
*negative* signal peak lifts the channel towards the gate: the effective
gate-source voltage is `−15 − Vpeak`. At −5 V peak that is −10 V, which is
exactly the J111's worst-case Vgs(off) — a part at that end of the spread
starts conducting on peaks.

Simulated, at 5 kHz, THD at the `HIGH` output with the band unmuted:

| signal at the output | J111, Vgs(off) = −10 V | J112, Vgs(off) = −5 V |
|---|---|---|
| 3.7 V pk | 0.016 % | 0.021 % |
| 4.6 V pk | **2.28 %** | 0.006 % |
| 5.5 V pk | **7.27 %** | 0.035 % |
| 6.4 V pk | **11.24 %** | 0.004 % |

The article puts op-amp clipping around 3.5 V RMS ≈ 5 V peak, so **this
happens below the clipping ceiling**: the circuit would distort before it
ran out of headroom, and only on some units.

**The fix is `MMBFJ112` in place of `MMBFJ111`.** Same family, same
SOT-23, same pinout — the board is byte-for-byte the same size with the
same track and via count. J112 is specified Vgs(off) −1.0 to −5.0 V
instead of −3.0 to −10.0, so −15 V on the gate holds it off past any
signal the rails can produce.

It costs mute depth, because J112 allows 50 Ω of Rds(on) against J111's
30 Ω: **−45.7 dB instead of −49.9 dB**, against `R31`'s 10 kΩ. Four
decibels off an already-modest mute, to remove an 11 % distortion failure.

Reproduce with `python3 tools/gen_spice.py && python3 tools/run_sim.py`.

## 9. The power-down mute is late, and was described as fast

**Severity: low. Status: documented, not fixed — see below.**

`docs/circuit-notes.md` said `D4` "re-mutes fast when the rails collapse".
Simulated, it does not: the gate is referenced to the −15 V rail, so it can
only reach the JFET's turn-on threshold once the rail has already fallen
that far. Rail voltage at which the mute actually engages:

| corner | mutes at | rail already lost |
|---|---|---|
| J111 −10 V | −9.3 V | 38 % |
| J111 −3 V | −2.0 V | 87 % |
| J112 −5 V | −3.9 V | 74 % |
| J112 −1 V | −0.3 V | 98 % |

Both parts are late at their easy-to-pinch corner, so this is not
something the J112 swap introduced — it is how a rail-referenced gate
behaves. **The power-up mute is the one that matters and it works**
(−45.7 dB while the rails settle, releasing after 0.06–0.9 s); the
power-down protection that actually does the work is the output coupling
caps, not the JFETs.

Not fixed because fixing it properly means detecting the rail falling —
a comparator or a supply-sense circuit — which is a new subsystem for a
transient the coupling caps already block the DC part of.

## 10. Assembly and mechanical

* **`U1`/`U2`/`U3` pin-1 orientation is unverified against JLCPCB's
  convention.** The SOIC-14 is a hand-drawn footprint. Check pin 1 in the
  assembly preview before paying — this is the classic way an assembled
  board comes back useless. The same goes for the polarity of `D1`–`D4`
  and the seven electrolytics.
* **The pots have no locating-boss holes.** There is no verified dual-gang
  mechanical drawing to place them from, and shipping a hole in the wrong
  place is a re-order where a missing one is a hand drill. Check your parts:
  if yours have bosses, drill for them before soldering, or the pots will
  not sit flat.
* **The controls are right-angle parts on the front edge**, so the board
  lies **flat in the enclosure, perpendicular to the panel**, with shafts
  and plungers coming out of the board's edge and through the panel. (This
  entry used to say the opposite — that the shafts stand perpendicular to
  the PCB and the board mounts behind the panel — which stopped being true
  when the controls became edge-mount parts and nothing caught it. The
  hole positions are in
  [`panel-drilling.md`](panel-drilling.md), generated from the placement.)
* **The four mounting holes are no longer at fixed corners.** They start
  3.56 mm in and move as far as they must to clear the pinned edge rows,
  so the set is not symmetric. Drill from `panel-drilling.md`, not from
  the corners. **Status: FIXED** — they used to sit 0.69 mm from the board
  edge, which passes every fab limit and cracks when the screw is
  tightened.
* **`C569866` (33 nF) has 2001 in stock** and the board uses 6. That is
  about 330 boards' worth — fine for one build, worth checking before a
  batch. It is the thinnest line in the BOM.
* **A dead part number is now a build failure, not a note.** `C46550416`
  (10 µF) covered seven designators and returned *zero* LCSC search
  results — an end-of-lifed number, not a temporary stock-out — while
  every geometric check passed, because nothing about the copper was
  wrong. Replaced with `C2858858` (KNSCHA 10 µF 50 V, same D5×L5.4 mm
  package, 50 000 in stock), and `validate_fab.py --online` now *fails* on
  a part it cannot find rather than printing a note under thirty lines of
  healthy stock figures.

---

## What is *not* a problem

Worth saying explicitly, because these look alarming and are not:

* **Trace widths.** 12 mil signal and 16 mil power carry 13–21× the
  worst-case current by IPC-2221. They were chosen for pad proportion, not
  capacity.
* **Two 33 nF in parallel** for each tuning capacitor. Deliberate: it
  keeps every tuning cap the same part from the same reel, and matching
  matters far more here than absolute value.
* **Per-output grounds.** Each output terminal carries its own ground
  return precisely so three amplifiers do not share one and form a hum
  loop.
* **Same-net vias 0.43 mm apart** — fixed, and it was a drilling limit
  rather than an electrical one.

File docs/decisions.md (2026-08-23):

# Decision log

Append-only, newest at the bottom. One entry per measurement, whether or
not it resulted in a change.

**Why this exists:** the expensive mistakes in this project have not been
bad code, they have been *re-doing work whose answer was already known* —
re-trying a knob that had been measured and rejected, or believing a change
had landed because a commit message said so. An entry here costs two
minutes and saves the next agent an afternoon.

**A rejected experiment is worth as much as an accepted one.** Write it
down even when — especially when — the answer was "no difference".

## Template

Copy this block, fill it in, append it at the end. Keep it short; the
numbers matter more than the prose.

```
### YYYY-MM-DD — one-line summary
**Question:** what you were trying to find out.
**Method:** the exact command(s), so it can be re-run.
**Result:** the numbers. Both arms if it was a comparison.
**Decision:** kept / reverted / needs more work — and why.
**Touched the placement?** yes (board re-searched, new SEED) / no.
```

---

### 2026-08-21 — the mute JFET was the wrong member of its family
**Question:** does the shunt JFET stay off on signal peaks?
**Method:** `python3 tools/gen_spice.py && python3 tools/run_sim.py`, which
sweeps level against both parts' datasheet corners.
**Result:** the gate rests at −15 V while the drain carries signal, so
Vgs(eff) = −15 − Vpeak. A worst-case J111 (Vgs(off) = −10 V) reaches
**2.28 % THD at 4.6 V pk and 11.24 % at 6.4 V**, below the op-amp clipping
ceiling. A J112 (−1.0 to −5.0 V) stays at 0.004–0.021 % everywhere. Cost:
mute depth −45.7 dB against −49.9, because J112 allows 50 Ω of Rds(on)
against 30.
**Decision:** kept. `MMBFJ112` (C258195) replaces `MMBFJ111`. Same die
family, same SOT-23, same pinout.
**Touched the placement?** No — identical board, same track and via count.

### 2026-08-21 — supply rails are not worth widening
**Question:** are the 16 mil power traces thick enough?
**Method:** measured routed length per net out of the committed board JSON,
then IPC-2221 for capacity and ρL/A for drop.
**Result:** +15 V is 216 mm of 0.406 mm trace = 261 mΩ, carrying 48 mA →
**12 mV** drop. IPC-2221 rates that trace at **1244 mA**, a 26× margin.
**Decision:** no change. The widths are set by pad proportion, which
remains the only reason to revisit them.
**Touched the placement?** No.

### 2026-08-21 — the input network needed a constraint, not a checker
**Question:** the render showed `R1` in the opposite corner from the op-amp
it biases. How bad is it?
**Method:** pad bounding box per net, out of the committed board.
**Result:** `N160_280` (input pin, 47 kΩ to ground, ahead of all gain)
spanned **49 mm**; `INPUT` (master volume wiper) spanned **73 mm**. Adding
them to `near` as `INPUT_NEAR` brought them to **9.2 mm and 18.4 mm**.
**Decision:** kept. Note that no geometric check had anything to say about
either — the requirement is local and physical, so it belongs in the cost
model, not in a checker.
**Touched the placement?** Yes. Re-searched; `SEED=1 ROUTE_SEED=0`,
145.8 × 66.5 mm, clean.

### 2026-08-21 — two hand-drawn footprints were wrong, from supplied datasheets
**Question:** do the hand-drawn footprints match the real parts? Five
datasheets were supplied: Alps RK097, RV09, ST MC33079, KNSCHA RVT 10 µF
(C2858858), CIXI MAIXU MX350-3.5 terminal block.
**Method:** read each mechanical drawing and compared with the emitted
geometry in `tools/gen_pcb_smd.py`.
**Result:**
* `fp_pot` (dual-gang, `VR1`/`VR2`) — drew 3 pins at **5.08 mm** with the
  gangs **5.08 mm** apart. Real: **six ø1 mm holes on a 2.5 mm grid**,
  three per gang at 2.5 mm, gangs 2.5 mm apart. Both pitches double. The
  body was 52 units wide on the same wrong reasoning; real is the same
  9.5 mm as the single-gang, 2.5 mm deeper.
* `fp_elec` — drew 2.03 × 2.54 mm pads on **4.32 mm** centres. Real
  (KNSCHA "Recommended Land Size", size 5): **1.6 × 3.0 mm on 3.0 mm
  centres**, gap 1.4 mm. Pads 1.3 mm too far apart.
* `fp_soic14` — **correct.** 1.27 mm pitch; pads inside IPC tolerance for
  E = 6.0 mm nominal.
* `fp_term` — **correct enough.** 3.50 mm real against 3.556 drawn, ø1.00
  real against 1.09 drawn; both inside the slack a ø0.8 mm pin leaves.
**Decision:** both fixed. Note for anyone tempted to trust the checkers
here: a footprint is self-consistent whatever its dimensions, so every
geometric check passes on a part that cannot be soldered. This class of
defect can only be found outside the repository.
**Touched the placement?** Yes — both footprints shrank. Re-searched;
`SEED=20 ROUTE_SEED=2`, 149.6 × 64.0 mm, clean at production settings.

### 2026-08-21 — the busiest parts had the least room (ESC_CAP 4 -> 7)
**Question:** are high-connection parts getting the space their routing
needs?
**Method:** measured pad-box gap to nearest neighbour per part on the
committed board, grouped by pin count; then A/B'd `ESC_CAP` over 16 seeds
at the ranking config.
**Result:** before, parts with >=6 pins sat a mean **2.32 mm** from their
nearest neighbour and parts with <=2 pins **3.32 mm** - backwards. `U3`
(14 pins) had 1.02 mm. `ESC_CAP` caps a side's escape demand at that many
track pitches, and it was 4, so a 7-pin SOIC face asked for no more than a
4-pin one.

| ESC_CAP | mean DRC | clean of 16 | mean height |
|---|---|---|---|
| 4 | 7.9 | 0 | 73.0 mm |
| 7 | 5.2 | 2 | 73.0 mm |
| 10 | 5.1 | 1 | 73.2 mm |

On the committed board the gap is now **3.14 mm** high-pin against
**3.34 mm** low-pin - the imbalance is essentially gone.
**Decision:** kept, `ESC_CAP=7`. Distinct from W_FILL (rejected twice):
that priced column AREA, this prices escape depth weighted by pin count.
**Touched the placement?** Yes. Re-searched; `SEED=41 ROUTE_SEED=5`,
147.3 x 68.3 mm, clean with no quality flags. Costs 5% area against the
board it replaces (2.3 mm narrower, 4.3 mm deeper). `SEED=39 ROUTE_SEED=6`
is the strictly-no-growth alternative: 145.3 x 65.8 mm, defect-free, high
-pin gap 2.88 mm, but it trips the wasted-rectangle quality note.

### 2026-08-23 — a two-pin part has two ways round (POLISH / flip_pass)
**Question:** spotted by eye on the render — `C14`'s trace to `R26`, the
part immediately to its right, leaves from its LEFT pad, so both its nets
cross and wrap around the body. Is the placer accounting for this at all?
**Method:** audited every two-pad part on the committed board, comparing
each one's nets' half-perimeter against the same part turned end for end.
Then a paired 3-arm A/B over 12 seeds at the ranking config, and a fourth
arm for the generalisation.
**Result:** no, it is not. `ROTS` gave chip passives and electrolytics
`(0, 90)`, on the reasoning that 180 is the same SHAPE — true, and beside
the point, because the two pads carry different NETS. **9 of 61 two-pad
parts sat the wrong way round, together 30.5 mm of half-perimeter**
(`C14` and `C15` worst at 6.1 mm each).

Two obstacles. `fp_chip` anchored its designator in the local frame, so
every chip on the board put its label on its own pad 1 at 180/270 and
failed the footprint probe — third instance of that bug class, now routed
through `silk_ref_beside()`. And the angles must NOT go to the anneal:

| arm | mean DRC | total |
|---|---|---|
| baseline `(0, 90)` | 8.42 | 101 |
| flip in a polish pass | **7.58** | **91** |
| flip in the anneal's move set | 9.67 | 116 |
| `POLISH=all` (every angle, every part) | 9.00 | 108 |

**Decision:** kept as `POLISH=flip` (default), with the angles in
`Part.flip_rots` so the anneal's trajectory is bit-for-bit unchanged.
`POLISH=all` measured and rejected — it accepts 21 moves against 6 on
seed 1 and routes worse than doing nothing, because a 180 on a two-pad
part changes only which pad carries which net while a 90 on a SOIC
changes which face has seven pins queuing to get out. `off` and `all`
kept so the measurement can be repeated.

A deterministic pass is the right shape regardless: `hpwl` is weighted
0.15 and contributes ~1533 of a ~490000 total, so the whole prize is ~18
cost units — 0.004%. The anneal is structurally unable to chase it.

Caveat, not glossed: seed 10 went **9 -> 16**. A flip moves the
designator, so it is not perfectly geometry-neutral.
**Touched the placement?** Yes, twice over — the silk fix moves every
chip's courtyard by half a unit, so the committed `SEED=41` board no
longer reproduces (157.2 x 74.2 mm instead of 147.3 x 68.3). Board search
pending; artifacts are stale until it lands.

### 2026-08-23 — flip_pass profiled: 2.53 s -> 0.42 s, output unchanged
**Question:** is the polish pass implemented efficiently, and should any
of it be in C?
**Method:** cProfile around `flip_pass` on a cold placement; then two
exact changes, each verified by diffing the run output before and after.
**Result:** 2.53 s, 5.6% of a search trial. 55% of it was `escape_of`,
called 21228 times — 244 `full_cost` evaluations x 86 parts. Two fixes:
`full_cost` was being called twice per candidate (once to score, once
after reverting, purely to restore derived state — now a copy), and
`escape_of` was 86 numpy calls on 86-element arrays where one (n, n)
masked reduction does the same arithmetic (`escape_all()`, checked
against the per-part version over 300 random layouts, worst difference
1.4e-14).

**2.53 s -> 0.42 s, 6.0x.** Output byte-identical on seeds 1-5 under both
`POLISH=flip` and `POLISH=all`: same parts turned, same half-perimeter,
same board.
**Decision:** kept. **C rejected**: `anneal.c` has the same cost model but
exports only `anneal`, and its `rot_base` excludes the flip angles, so
reuse needs a new export plus a `Cfg` change — structural risk in the one
struct that must stay field-for-field identical, for a term now at 1% of
a trial. Incremental scoring also rejected: it is not exact, so it would
change which flips are accepted and invalidate the A/B.
**Touched the placement?** No — that is the point, and it was checked
rather than assumed.

### 2026-08-23 — new committed board: SEED=17 ROUTE_SEED=0
**Question:** the silkscreen fix and the flip pass move every placement,
so the old `SEED=41` board no longer reproduces. What replaces it?
**Method:** ranked 24 seeds at the committed config (capped router, one
rip-up round, `ROUTE_SEED=0`), then confirmed the top four uncapped.
Chunked deliberately — this container is reprovisioned roughly hourly and
took two long searches with it, so verdicts are flushed per trial.
**Result:** ranking put `SEED=17` first at 2 problems (next best 3), and
uncapped it verifies **clean, 0 DRC problems**.

| | old board | new board |
|---|---|---|
| seed | `41` / `RS=5` | **`17` / `RS=0`** |
| size | 147.3 x 68.3 mm | **149.6 x 63.5 mm** |
| area | 10061 mm2 | **9500 mm2** (-5.6%) |
| tracks / vias | 238 / 179 | **227 / 159** |
| utilisation | 57% | 58% |

Wider by 2.3 mm, shallower by 4.8 mm, and 20 fewer vias. Every ranked
candidate was tagged "unrouted", which is the failure the cap manufactures
rather than a property of the placements — the usual reminder that the cap
ranks well and judges badly.
**Decision:** committed. `SEED`/`ROUTE_SEED` defaults pinned to 17/0.
**Touched the placement?** It IS the placement. `check_all.py` passes: no
drift, board verifies, fab limits and BOM clean.

### 2026-08-23 — why the flip pass stops: the designator is courtyard
**Question:** the polish ran and the board is clean, so is `C14` — the
part that started this — now the right way round? No. Why not?
**Method:** audited every two-pad part on the committed `SEED=17` board,
then scored each rejected flip term by term.
**Result:** **9 of 48 two-pad parts are still reversed, worth 23.5 mm**,
and `ov` blocks every one of them:

```
ref      d(total) d(hpwl mm)   terms that moved
C14        1518.3      -3.05   ov +1741, esc -221, hpwl -2
D1         9166.4      -3.40   ov +5508, near +3660, hpwl -2
R32        5864.6      -4.06   ov +5867, hpwl -2
R8         1956.0      -4.06   ov +1958, hpwl -2
```

`probe()` reads the courtyard off the emitted shapes and `shape_box()`
counts a silkscreen TEXT as body, so a footprint's courtyard is
asymmetric by about a label's height. Flipping moves that box to the
other side and into a neighbour: the wire gets shorter and the placement
becomes illegal.
**Decision:** not fixed here, written up instead. The constraint is
probably wrong — a label may not lie over foreign COPPER, which
`verify()` already checks exactly, but a label over a neighbour's silk is
what every board does. The fix is to split the term (courtyard overlap on
pads and body; a separate cheaper label-over-foreign-PAD term), not to
drop it. That moves every placement, so it needs its own search round and
its own A/B. On the task board as the top layout item.
**Touched the placement?** No.

### 2026-08-23 — POLISH=nudge: move as well as turn. Measured, rejected.
**Question:** the flip pass is blocked by courtyard overlap on 9 parts
(previous entry). If a part cannot turn where it stands, can it turn a
track pitch to the left instead? That needs no cost-model change, no
`anneal.c` change and no check weakened.
**Method:** `POLISH=nudge` tries the 180 at the current position and at
each of the eight neighbours one track pitch away. 13 seeds, ranking
config, against the `flip` baseline.
**Result:** it does step aside — 25 to 98 moves accepted a board where
`flip` accepts 5 to 9 — and it routes worse.

| POLISH | total DRC over seeds 1-12 | |
|---|---|---|
| `flip` | **91** | |
| `nudge` | 96 | better 3, worse 6, tied 3 |

`SEED=17`, the committed board, goes from 2 problems to 5.
**Decision:** rejected; default stays `flip`. The move count is the tell:
this is a second greedy search over POSITION, and position is what the
anneal already spends 60000 moves on. Turning a part in place is nearly
free geometrically and can be taken on the surrogate; moving it is not.
Sixth time this trade has been lost here (MOVES, RESTARTS, W_FILL twice,
POLISH=all, and now this). Mode kept so the measurement can be repeated.
The finding stands: fix the courtyard, not the pass that trips over it.
**Touched the placement?** No — default unchanged, so `SEED=17` is
untouched.

### 2026-08-23 — the courtyard fix: correct, measured, reverted
**Question:** the overlap term treats a designator as solid, which blocked
9 of 48 two-pad parts from turning the right way round. Fix it so a label
blocks copper rather than another label.
**Method:** priced overlap as part i's FULL extent against part j's HARD
box (pads and body, no silk text), both ways round — which needs no new
term and forbids exactly the right things. Implemented in `probe()`,
`Placer`, `anneal.c` (`Cfg` verified by compiling it and comparing
`sizeof` and every offset against `ctypes`: 344 bytes both sides) and
`verify()`. 12 seeds at the ranking config in two size-weight settings,
then uncapped confirms on the smallest candidates.
**Result:** it works as intended — `silk ... sits over` never fired,
`flip_pass` went from 5-9 moves to up to 24 — and it loses.

| arm | total DRC | mean area |
|---|---|---|
| baseline (full-against-full, `W_H=400`) | **91** | 10465 mm2 |
| courtyard fix, `W_H=400` | 115 | 10212 mm2 |
| courtyard fix, `W_H=150` | 84 | 11079 mm2 |

At `W_H=400` the freed space goes straight into a smaller board —
`SEED=12` at **8384 mm2**, 12% under the shipped board — and uncapped
none of the small ones route (`+15V`, `N1400_900`, `HIGH_VOL`/`MG2` each
left in two pieces). Its only clean board is 10706 mm2, 13% bigger than
the incumbent. At `W_H=150` it wins on count and pays 6% more area, best
candidate 10461 mm2.
**Decision:** reverted. A board search ships the smallest CLEAN board, not
a mean, and on that metric the correct model loses in every configuration
while the incorrect one holds 9500 mm2 verified clean. Being right about
the geometry does not entitle a change to ship. Done as a clean revert of
one self-contained commit (131a7ea) so retrying it is a `git revert` away.
If retried: re-tune `W_H` (it is coupled to the courtyard and was
calibrated against the old one) and use a full-width seed field — 12
seeds against the incumbent's 24 is not a fair budget.
**Touched the placement?** Net zero. `check_all.py` passes with a cold
cache: `SEED=17`, 149.6 x 63.5 mm, verifies clean.

### 2026-08-23 — a stale placement cache reported a board that did not exist
**Question:** a parallel route-order batch reported `SEED=15` as
**194.6 x 66.5 mm with 5 DRC problems** on two of four trials, and
145.3 x 62.2 mm on the other two. Same seed. Same code. Which is real?
**Method:** re-ran the two odd trials alone with `.place-cache` cleared,
and ran six cold-cache placement-only trials of the same seed back to
back.
**Result:** the six isolated runs are byte-identical (145.3 x 62.2 every
time), so the placer is deterministic — this is NOT the set-iteration
non-determinism this file documents. Re-run with the cache cleared,
`RS21` gives **145.3 x 62.2 and 2 problems** instead of 194.6 x 66.5 and
5. The cache had served a pose computed by code that no longer existed,
and the run printed "reusing the cached layout" and routed it.

The new trigger is worth knowing: **the container image ships a
`.place-cache` directory** (entries dated days before this session), and
the repo is re-cloned at a pinned revision on every reprovision, so a
fresh session can start with a cache full of poses from code that is no
longer in the tree.
**Decision:** `_place_key()` now hashes `gen_pcb_smd.py` as well as
`place.py`, `anneal.c` and `canneal.py`. `GEOM` covered footprint
geometry, but everything else that file decides before the anneal runs —
pinned rows, edge margins, mounting-hole keepouts, which parts are
grouped — was outside the key. Costs a re-placement whenever the file is
edited, which is a few seconds; the alternative is routing a layout from
a different codebase and believing the number. Third time a cache has
served a stale answer here.
**Touched the placement?** No. `check_all.py` passes with the cache
cleared: `SEED=17`, 149.6 x 63.5 mm, verifies clean, no drift.

### 2026-08-23 — correction: the cached-pose diagnosis was not proven
**Question:** the previous entry blamed a stale `.place-cache` for
`SEED=15` reporting a 194.6 x 66.5 mm board. Is that actually the
mechanism?
**Method:** tried to reproduce it. Also tested a second hypothesis — that
four concurrent trials race on building `tools/_anneal.so`, and a process
loading a half-written library falls back to the PYTHON annealer, which
`CLAUDE.md` says gives a different board for the same seed.
**Result:** the build race is **disproved**. Four concurrent cold builds
of the `.so`, same seed, all produced 145.3 x 62.2 and none printed the
fallback warning. And the key-collision story does not hold up either:
`_place_key()` hashes the netlist, and the stale entries were written
against a netlist with 83 parts against today's 86, so their keys cannot
match.

What survives is one causal observation and no mechanism: clearing
`.place-cache` changed the SAME trial from 194.6 x 66.5 / 5 problems to
145.3 x 62.2 / 2, and six isolated cold-cache runs of that seed are
byte-identical. The offending entry was deleted before it could be
examined.
**Decision:** stop guessing at the mechanism and make the failure
impossible to ship instead. `_cached_pose()` now rejects any cached pose
whose part set is not exactly this board's, naming what is missing or
unknown, and recomputes. Tested by planting a doctored entry both ways:
each is rejected and the correct board is produced. Keeping the
`gen_pcb_smd.py` addition to the key from the previous entry — it is
sound hardening — but it should NOT be credited with fixing the observed
anomaly, because nothing here has established what did.
**Touched the placement?** No. `check_all.py` passes with the cache
cleared.

### 2026-08-23 — SEED=15 diagnosed and dropped: congestion, not a pocket
**Question:** `SEED=15` (9038 mm2, 5% smaller than the shipped board) came
within one net of clean on two independent route orders, both failing on
`N570_920` with `R13.1` stranded. Is that a structural pocket worth
opening, or is the placement simply full?
**Method:** rebuilt `SEED=15 ROUTE_SEED=12` in an isolated copy of the
tree (so the committed artifacts could not be touched), reproduced the
failure exactly, and mapped the copper around `R13.1` layer by layer.
Then compared which nets fail across all 18 route orders.
**Result:** it is congestion, and the evidence is two-sided.

Locally, `R13.1` is a top-layer SMD pad with **no via within 6.6 mm** in
any direction. Inside that window the top layer already carries 12 foreign
track segments and 8 foreign pads, the bottom 6 segments, Inner2 8. Nearest
foreign copper edge: 1.02 mm right, 2.59 mm down. The router never found
room to drop a via, and the top-layer channels were spoken for. Its two
partners are 10.8 mm right (`U2A.3`) and 19.8 mm left (`R14.1`).

Globally — and this is what settles it — **the failing net is different
almost every time.** Across 18 uncapped route orders the casualties
include `N570_920`, `N1280_900`, `N2150_1550`, `N530_100`, `N530_700`,
`N1580_640`, `MID_MUTE`, `LOW_MUTE`, `HIGH_MUTE`, `MUTE_SS`, `MG2` and
`+15V`. A structural pocket strands the same pad whatever the order; this
placement is about one net over capacity and route order only chooses
which net loses.

For scale, it carries slightly MORE copper in less area than the board it
would replace: 233 tracks / 163 vias against 228 / 159.
**Decision:** dropped. Making it routable means giving it room, at which
point it stops being smaller. `SEED=17` at 9500 mm2 verified clean stands
as the shipped board. The size search is closed at 60 seeds ranked and 18
uncapped route orders on the best sub-9500 candidate.
**Touched the placement?** No — the whole diagnosis ran in a scratch copy.

### 2026-08-23 — every terminal prints its designator over its own pin name
**Question:** found by reading the render, not by any check: the rear row
shows "J5LOW", "J4MID", "J2IN", "J1+15". Are those labels really
colliding, and can it be fixed?
**Method:** measured every silk-label pair on the board; then tried the
two ways the designator can clear the name row, pricing each with a
re-search rather than at one seed (a footprint silk change moves every
placement).
**Result:** five real collisions, all the same defect — each screw
terminal's designator overlaps its own first pin name by 0.58-0.98 mm
horizontally and 1.08 mm vertically. `verify()` cannot see it: it checks
silk against COPPER, and two labels on top of each other is legal
copper-wise and useless to a human.

Both fixes cost real board:

| fix | result |
|---|---|
| designator above the name row | `SEED=17` 149.6 x 63.5 -> **168.7 x 79.0 mm** |
| designator beside the block | 24 seeds re-ranked; best routable **11858 mm2 @ 1 DRC**, next 12008 @ 3. Small ones (9513, 9542) route at 10-12. |

Against the incumbent's 9500 mm2 verified clean, that is **+25% board** to
un-overlap a designator. The pin names — the labels that actually tell you
which terminal drives which amplifier — remain readable either way, and
the designators are on the assembly drawing and in the CPL.

The geometry says why there is no free fix: the block is 14 units (3.556
mm) per pin and `LABEL_SIZE` text is ~3.1 units per character, so "GND"
alone eats 9.3 of a 14-unit pitch. There is no room on that line for a
designator, and the only clear space is outward, which is what costs.
**Decision:** refused, and made VISIBLE instead. `validate_fab.py` gains
`check_silk_overlaps()`, which reports every overlapping label pair as a
note with its dimensions. The defect is now measured on every run instead
of waiting for someone to read a render.
**Touched the placement?** No — the footprint change was reverted.
`check_all.py` passes with a cold cache: `SEED=17`, 149.6 x 63.5 mm, clean.

### 2026-08-23 — KiCad export, and the netlist bug it found
**Question:** deliver the schematic in KiCad (or Altium, or Specctra).
**Method:** Altium `.SchDoc` is a binary OLE compound document — a poor bet
without Altium. Specctra `.dsn` is a BOARD format and cannot carry a
schematic. So KiCad: `tools/gen_kicad.py` reads the geometry
`gen_schematic.build()` already lays out — every pin in absolute
coordinates, every wire polyline, every label, every junction — and
translates it, rather than re-deriving a layout from the netlist.
Symbols are emitted one per INSTANCE and embedded in the file's own
`lib_symbols`, so nothing depends on the reader's libraries and no
rotation or mirroring can go wrong. EasyEDA units are 0.254 mm exactly, so
everything lands on KiCad's 2.54 mm grid with no rounding; symbol space is
Y-UP where sheet space is Y-down, which is the classic way a translated
symbol comes out mirrored.

Checked the way `verify()` checks the board — by measuring the artifact.
`verify_connectivity()` parses the emitted file back with a real
S-expression parser, rebuilds connectivity from geometry alone, and
refuses to write unless the result matches the schematic's own netlist.
**Result:** on its first run it disagreed, and it was right.
**Three GND flags were attached to nothing.** `extract_netlist()` looks a
label up by its exact coordinate in a DSU containing only wire VERTICES
and pin dots, so a label landing mid-segment joined nothing and named a
net that did not exist. The three affected are the GND flags on the mute
switches' mounting lugs, which sit in the middle of the wire linking lug 7
to lug 8 — so **the six switch mounting lugs shipped as isolated two-pad
nets (`N200_2216` and friends) instead of ground**, contradicting the
drawing. Both EasyEDA and KiCad connect a label wherever it lands on a
wire; this did not.
**Decision:** fixed at the root — `split_wires()` now promotes net-label
positions to wire vertices, like pin dots and wire ends. GND goes from 37
pins to 43, the three orphan nets disappear, 67 nets become 64.
**Touched the placement?** Yes, the netlist changed — and it came out
free: **149.6 x 63.5 mm, still verified clean, with LESS copper** (223
tracks / 158 vias against 228 / 159), because the lugs now reach the pour
instead of needing three little routed nets.

### 2026-08-23 — KiCad routing seed (placed, never wired)
**Question:** produce a `.kicad_pcb` to feed an external routing AI: our
board size, edge components placed on the board, everything else outside
it, and nothing wired.
**Method:** `tools/gen_kicad_pcb.py` reads the committed `pcb/*.json`
rather than re-running the board generator, so the export cannot describe
a board that was never built. The edge rows are read out of
`gen_pcb_smd.py` with `ast` — `PANEL_ORDER` + `REAR`, without executing
it — because deriving them geometrically does not work: pot pads sit back
from the edge their bodies touch, so a "within 4 mm of the edge" test
returns `C3B` and `R14` and misses every pot.
**Result:** 149.6 x 63.5 mm outline; 14 edge parts at their committed
positions (VR1-VR6, SW1-SW3, J1-J5); 72 parts parked on a grid outside;
64 nets on 242 pads; 4 mounting holes as NPTH so nothing routes through a
screw. **Zero tracks, zero vias, zero zones** — the ground pour is
deliberately absent too, since pouring is the router's job here.

Checked by re-reading the emitted file, not by trusting the writer: no
copper primitives of any kind, footprint and pad counts match the board,
pad nets identical to the board's, every edge part inside the outline and
every other part clear of it.
**Decision:** kept, and wired into `check_all.py` so it cannot drift.
**Touched the placement?** No — it is a read-only export of the committed
board.

### 2026-08-23 — the KiCad exports were missing components (router import)
**Question:** imported into a routing tool, which reported `U2`, `U3` "and
loads of other components" missing. Ours or theirs?
**Method:** compared the reference designators in the two emitted files.
**Result:** ours, and two separate bugs.

**1. Multi-unit parts were emitted as separate components.** The schematic
draws `U1A`..`U1D` and `VR1A`/`VR1B`; the board has one SOIC-14 called
`U1` and one pot called `VR1`. KiCad ties a symbol to a footprint by
REFERENCE, so 17 schematic parts had no footprint and 6 footprints
(`U1`-`U3`, `VR1`, `VR2`, plus the one below) had no symbol. Now emitted
as proper multi-unit symbols: one `lib_symbol` per physical part with a
sub-symbol per unit, and instances carrying `(unit N)` and the physical
reference.

The split cannot be guessed from the name — `C3A`/`C3B` look exactly like
`U1A`/`U1B` and are two real, separate capacitors — so `unit_map()` asks
the BOARD which designators physically exist.

**2. `J6` was named `LD1`.** `read_board()` took the first silk text that
looked like a designator, and `J6`'s footprint prints its pin labels
`LD1`/`LD2`/`LD3` first. `TEXT~P` is the designator; `TEXT~L` is a plain
label. So the board carried a part that does not exist and the schematic's
`J6` had no footprint.

Both files now agree exactly: **86 components each, no schematic part
without a footprint, no footprint without a symbol.**
**Decision:** fixed, and the verifier extended - it now maps each unit's
pins back through the unit map, so a section/part naming mismatch fails
the build instead of shipping. Also added `kicad/` to `check_all.py`'s
GENERATED list: it was being classed as SOURCE, so a change there was
never reported as drift.
**Touched the placement?** No.

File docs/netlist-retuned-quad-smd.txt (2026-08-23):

Netlist extracted from the generated schematic geometry
variant: esp-p148-3way-crossover-retuned-quad-smd
  High/Mid  195 Hz - 1.03 kHz   R7, R8 = 4.7k   C1, C2 = 33nF
  Mid/Low   73 Hz - 186 Hz  (C3, C4 = 2 x 33nF)   R17, R18 = 13k   C3, C4 = 33nF
========================================================

+15V       C11.1  C5.1  C7.1  C9.1  J1.1  R37.1  R38.1  R39.1  U1A.4  U2A.4  U3D.4
-15V       C10.2  C12.2  C6.2  C8.2  D4.1  J1.3  R34.2  R35.2  R36.2  R40.1  U1A.11  U2A.11  U3D.11
GND        C10.1  C11.2  C12.1  C16.2  C5.2  C6.1  C7.2  C8.1  C9.2  J1.2  J2.2  J3.2  J4.2  J5.2  J6.4  Q1.2  Q2.2  Q3.2  R1.2  R13.2  R28.2  R29.2  R3.2  R30.2  SW1.1  SW1.7  SW1.8  SW2.1  SW2.7  SW2.8  SW3.1  SW3.7  SW3.8  U1C.10  U1D.12  U2B.5  U2C.10  U2D.12  U3D.12  VR3.3  VR4.3  VR5.3  VR6.3
HIGH       C13.2  J3.1  R28.1
HIGH_MUTE  Q1.1  R31.2  U3A.3
HIGH_PRE   R9.2  VR3.1
HIGH_VOL   R31.1  VR3.2
INPUT      C0.1  VR6.2
INPUT_PRE  J2.1  VR6.1
LD1        J6.1  SW1.6
LD2        J6.2  SW2.6
LD3        J6.3  SW3.6
LOW        C15.2  J5.1  R30.1
LOW_MUTE   Q3.1  R33.2  U3C.10
LOW_PRE    R22.2  VR5.1
LOW_VOL    R33.1  VR5.2
LP1        C2.2  R11.1  R15.1  R6.2  U1D.14
LX1        R37.2  SW1.3
LX2        R38.2  SW2.3
LX3        R39.2  SW3.3
MG1        D1.2  Q1.3  R34.1  SW1.4
MG2        D2.2  Q2.3  R35.1  SW2.4
MG3        D3.2  Q3.3  R36.1  SW3.4
MID        C14.2  J4.1  R29.1
MID_MUTE   Q2.1  R32.2  U3B.5
MID_PRE    R19.2  VR4.1
MID_VOL    R32.1  VR4.2
MUTE_SS    C16.1  D1.1  D2.1  D3.1  D4.2  R40.2
N1100_300  C1.2  R4.2  U1C.8  VR1B.1
N1100_900  C3A.2  C3B.2  R14.2  U2B.7  VR2B.1
N1280_300  R8.1  VR1B.2  VR1B.3
N1280_900  R18.1  VR2B.2  VR2B.3
N1400_300  C2.1  R8.2  U1D.13
N1400_900  C4A.1  C4B.1  R18.2  U2C.9
N1580_640  C4A.2  C4B.2  R12.2  R20.1  R24.1  U2C.8
N160_280   C0.2  R1.1  U1A.3
N1680_900  R20.2  R21.1  U2D.13
N1850_900  R21.2  R22.1  U2D.14
N2150_1250 R25.1  U3A.1  U3A.2
N2150_1400 R26.1  U3B.6  U3B.7
N2150_1550 R27.1  U3C.8  U3C.9
N2150_1700 U3D.13  U3D.14
N2260_1250 C13.1  R25.2
N2260_1400 C14.1  R26.2
N2260_1550 C15.1  R27.2
N350_300   R2.1  U1A.1  U1A.2
N530_100   R2.2  R5.1  R6.1  U1B.6
N530_700   R12.1  R15.2  R16.1  U2A.2
N570_320   R3.1  R4.1  U1B.5
N570_920   R13.1  R14.1  U2A.3
N680_300   R10.2  R5.2  R9.1  U1B.7  VR1A.1
N680_900   R16.2  R19.1  R23.2  U2A.1  VR2A.1
N830_300   R7.1  VR1A.2  VR1A.3
N830_900   R17.1  VR2A.2  VR2A.3
N950_300   C1.1  R7.2  U1C.9
N950_900   C3A.1  C3B.1  R17.2  U2B.6
SW1_NC1    SW1.5
SW1_NC2    SW1.2
SW2_NC1    SW2.5
SW2_NC2    SW2.2
SW3_NC1    SW3.5
SW3_NC2    SW3.2
TP1        R10.1  R11.2  TP1.1
TP2        R23.1  R24.2  TP2.1

64 nets, 97 parts, 242 component pins, 71 junctions

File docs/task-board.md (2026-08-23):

# Task board

Open work, sized for one agent per item. **Read `AGENTS.md` first.**

Every task is marked **[serial]** or **[parallel]**:

* **[serial]** moves the parts. It invalidates the placement, forces a
  board re-search of tens of minutes, and produces a *different board*.
  Only one of these may be in flight at a time — if two agents do it, the
  second one's search is thrown away. Claim it before starting.
* **[parallel]** cannot move the parts. Any number of these can run at
  once.

Finish every task by running `python3 tools/check_all.py` and appending to
`docs/decisions.md`.

---

## Blocked on physical parts or datasheets

These cannot be closed by an agent. They need the parts in hand or a
mechanical drawing. See the top of this file's companion discussion in
`README.md` ("Of the routed board").

* ~~Confirm the dual-gang pot footprint.~~ **DONE** — and it was wrong by
  2× in both axes. Fixed from the Alps RK097 catalogue drawing. See
  `docs/decisions.md`.
* ~~Confirm the SOIC-14 land pattern.~~ **DONE** — correct.
* ~~Confirm the electrolytic land pattern.~~ **DONE** — and it was wrong;
  pads were 1.3 mm too far apart. Fixed from the KNSCHA datasheet.
* ~~Confirm the screw terminals.~~ **DONE** — 3.50 mm real against 3.556
  drawn, inside the slack a ø0.8 mm pin leaves in a ø1.09 mm hole.
* **Confirm the pot's locating bosses.** The RK097 drawing shows the PCB
  hole pattern but this board drills no boss holes. If the parts bought
  have bosses, they need holes — check before soldering.
* **Measure the shaft and plunger heights above the board** and add them to
  `docs/panel-drilling.md`. That file deliberately omits them today,
  because inventing the one dimension nobody can check is worse than
  leaving a gap.

---

## Ready to work on

### [parallel] Verification and analysis

* **Add a THD-capable op-amp model.** `sim/models.lib` is a behavioural
  macromodel with no device-level nonlinearity, so `run_sim.py` cannot
  predict distortion — only topology. A real MC33079 (or a generic
  transistor-level) model would let the suite report a distortion figure.
  Say clearly in the docs what the new model can and cannot claim.
* **Simulate crosstalk between bands.** Three outputs, one ground plane,
  per-output ground returns. Nothing has measured it.
* **Simulate PSRR** — inject ripple on the rails and measure what reaches
  an output. The bulk and per-IC decoupling were added on reasoning, never
  measured.
* **Extend `run_sim.py` to sweep the volume pots**, not just the frequency
  pots. The band trims are attenuators feeding a buffer; confirm nothing
  interesting happens at the extremes.
* **Check the mute chain's dry-circuit margin by simulation** rather than by
  the hand calculation now in `docs/circuit-notes.md`.

### [parallel] Checks worth adding to `validate_fab.py`

* **Silkscreen legibility against the courtyard**, not just against pads —
  a designator that lands on a neighbouring part's body is still bad.
* **Acid-trap / acute-angle detection** on the routed copper.
* **Assert the CPL rotations** against each footprint's pin-1 direction, so
  a footprint edit that rotates a part is caught.

### [parallel] Documentation

* **A build guide.** The docs explain the design thoroughly and the
  assembly barely: what to solder first, how to set the two frequency
  knobs, what the test points are for, how to check it works before
  connecting amplifiers.
* **Trim `CLAUDE.md`.** It is over 1300 lines and mixes durable principles
  with narrative history. Split the principles from the war stories
  without losing any measurement.

### [serial] Layout — one at a time, claim first

* **Move `J6` to a board edge.** The LED loom connector currently sits
  mid-board, so the loom crosses the layout to reach the panel. It is
  anchored to `SW2` by `MUTE_NEAR`. Cost: a re-search.
* **Retry the courtyard split, with the two things the first attempt
  could not afford.** BUILT AND REVERTED once already — see
  `docs/decisions.md` and `CLAUDE.md`. `git revert 131a7ea` brings the
  whole implementation back (probe, Placer, `anneal.c` `hbox`, `verify()`,
  cache key), so do NOT re-derive it. It is correct and it lost: the freed
  space goes into a smaller board that will not route, and its only clean
  board was 13% bigger than the incumbent. What was NOT tried, and must be
  before it is judged again: a `W_H` re-tune (400 was calibrated against
  the old courtyard, and the two are coupled) and a full-width seed field
  (12 seeds against the incumbent's 24 is not a fair budget). Background
  on why it matters: `probe()` reads the courtyard off the
  emitted shapes and `shape_box()` counts a silkscreen TEXT as body, so a
  part's courtyard is asymmetric by about a label's height. Turning a
  two-pin part end for end therefore pushes that box into a neighbour, and
  the overlap term rejects the move. On the committed board **9 of 48
  two-pad parts are still the wrong way round, worth 23.5 mm of
  half-perimeter, and every single one is blocked by `ov`** — `C14` by
  +1741, `R32` by +5867. The constraint is wrong: a label may not lie over
  foreign COPPER (a pin that cannot escape — `verify()` already checks
  that exactly), but a label over a neighbour's silk outline is what every
  board does. Do NOT just drop the check: split it into courtyard overlap
  on pads and body, plus a cheaper term for label-over-foreign-PAD. Moves
  every placement, so it needs its own search round and its own A/B.
  Evidence and the per-part cost breakdown are in `CLAUDE.md`.
* ~~**Try to beat 149.6 × 63.5 mm (9500 mm²).**~~ **CLOSED — do not
  re-run this without a new idea.** 60 seeds ranked and 18 uncapped route
  orders swept on the best sub-9500 candidate. `SEED=15` (9038 mm², 5%
  smaller) gets within one net twice and was diagnosed: `R13.1` has no via
  within 6.6 mm and the channels around it are taken, and across the 18
  orders **twelve different nets** fail — congestion about one net over
  capacity, not a pocket, so route order only picks the casualty. Giving it
  room makes it stop being smaller. Note also that the expansion cap is a
  bad ranker for ROUTE ORDERS (`RS12` scores 11 capped, 2 uncapped) even
  though it is the best ranker across seeds — sweep orders uncapped.
* **Reduce the largest empty rectangle** (29 × 28 mm at present, 58 %
  utilisation). Note that `W_FILL` has been measured **twice** and rejected
  both times — read the entry in `CLAUDE.md` before attempting anything
  that prices area.

---

## Do not do these

Measured, rejected, and documented in `CLAUDE.md`. Reopening one needs new
evidence, not a new idea.

* Adding a `BOARD_W`/`BOARD_H` knob.
* Raising `MOVES` or `RESTARTS`.
* Capping `MAX_EXPAND` in production routing.
* A column-load / area-filling placement term (`W_FILL`).
* `GRID=0.5` for search ranking.
* Octilinear routing, cheap vias, or layer-grain routing.
* Negotiated-congestion routing at per-net granularity.

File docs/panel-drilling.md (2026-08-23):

# Front-panel drilling

Generated by `tools/gen_pcb_smd.py` from the placement that produced
the copper - regenerate the board and this file follows it.

Board is **149.6 mm wide x 63.5 mm deep**, mounted flat and
perpendicular to the panel, controls along the front edge.

All X are measured **from the left-hand edge of the board**, looking
at the front panel from the front, with the board's left edge aligned
to the panel's reference point. Left to right the row reads MASTER,
then LOW -> HIGH, each mute button beside the volume trim it mutes.

| Designator | Control | X from left edge | Passes through | Suggested hole |
|---|---|---|---|---|
| `VR6` | MASTER | **9.6 mm** | 6 mm shaft | 7.0 mm |
| `SW3` | MUTE LO | **23.8 mm** | 2.8 mm plunger | 4.0 mm |
| `VR5` | LOW VOL | **38.0 mm** | 6 mm shaft | 7.0 mm |
| `VR2` | MID/LOW freq | **58.4 mm** | 6 mm shaft | 7.0 mm |
| `SW2` | MUTE MID | **72.6 mm** | 2.8 mm plunger | 4.0 mm |
| `VR4` | MID VOL | **86.8 mm** | 6 mm shaft | 7.0 mm |
| `VR1` | HIGH/MID freq | **107.1 mm** | 6 mm shaft | 7.0 mm |
| `SW1` | MUTE HI | **121.4 mm** | 2.8 mm plunger | 4.0 mm |
| `VR3` | HIGH VOL | **135.6 mm** | 6 mm shaft | 7.0 mm |

Centre-to-centre spacing, in order: 14.2, 14.2, 20.3, 14.2, 14.2, 20.3, 14.2, 14.2 mm.

Two pitches, deliberately: 20.3 mm between two knobs (`PANEL_PITCH`, a human-factors
number - a knob for a 6 mm shaft is 15-20 mm across), and 14.2 mm wherever a
button is one of the pair (`SWITCH_PITCH`) - a 2.8 mm plunger does not
need a knob's worth of panel.

**The height of each axis above the board is not given here.** It is a
datasheet number for the specific pot and push-switch, and this board's
pot body is an unverified hand-drawn footprint (see
[`pcb-notes-smd.md`](pcb-notes-smd.md)). Measure it once from the real
parts; it is the same offset for the whole row.

## Mounting holes

3.2 mm diameter (M3 clearance), measured from the same left edge and
from the REAR edge. **X is fixed** at 2.80 mm from each side: the board
is widened so that strip contains no components, which is what puts
every part inboard of every screw. Y starts 3.56 mm in and moves only
as far as it must to clear the two pinned rows, so the two on one side
may not match the two on the other - use these numbers, not the corners.

| X from left | Y from rear | Board material outside it |
|---|---|---|
| 2.80 mm | 3.56 mm | 1.20 mm |
| 2.80 mm | 59.94 mm | 1.20 mm |
| 146.81 mm | 3.56 mm | 1.20 mm |
| 146.81 mm | 59.94 mm | 1.20 mm |

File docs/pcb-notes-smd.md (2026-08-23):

# SMD board — retuned-quad-smd, for JLCPCB fab + assembly

`pcb/esp-p148-3way-crossover-retuned-quad-smd-pcb.json`, generated by
`tools/gen_pcb_smd.py`. **149.6 × 63.5 mm**, four layers, fully routed,
with nine front-panel controls on the board - a frequency pot and a volume
trim for each of the three bands, a master volume, and a mute button per
band - trace width matched to purpose (12 mil signal, 16 mil +15V/-15V/GND), and
45° chamfered corners throughout.

Beyond the filter it carries buffered outputs with build-out resistors, DC
blocking and bleeders, bulk and per-IC supply decoupling, and per-output
muting with power-up soft start. Which parts do which job is listed block
by block in
[`circuit-notes.md`](circuit-notes.md#function-blocks-on-the-smd-board).

SMD board

One channel. Build two for stereo.

## What is verified

The generator routes the board and then checks it with geometry that does not
reuse the router's own bookkeeping. On the current output:

```
board 149.6 x 63.5 mm | 86 footprints | 242 pads | 227 tracks | 159 vias
verified: all nets connected, all clearances >= 8 mil, no unrouted nets,
          pads match the schematic exactly
```

**The pinned rows cost height, but far less than the first board that
had them suggested.** The board before the rows existed was 141.7 × 70.4 mm
and verified clean, but it did that partly by putting parts in the strip in
front of the pot row - where the front panel goes - and behind the connector
row. The first clean board with the rows in paid 14 mm for forbidding that
(70.4 → 84.8); the current one pays 2 mm less than the free-terminal board
ever did, at 68.1 mm. The cost was mostly the seed, not the constraint -
which is worth knowing before treating a single search result as the price
of a requirement.

## Ground is fanned out, not repaired

Every SMD ground pad gets **its own via to the plane before a single signal
net is routed**. A through-hole pad needs none of this - it is already on
every layer, plane included.

This is standard practice, and on this board it is also the difference
between a clean verify and a permanent defect. Ground used to be repaired
AFTERWARDS, by looking for somewhere to put a via once the traces were
down, and by then the answer at the worst pads was "nowhere":

```
plane via Q1.2:   no site in 33 candidates (clearance x32, drill keepout x1)
plane via U2D.12: no site in 33 candidates (clearance x27, drill keepout x6)
```

Those refusals are exact geometry, not the router's bookkeeping: signal
traces had been routed hard against those pads and no 0.71 mm via pad plus
0.2 mm of clearance fits near them any more. Nothing threads to a pad that
is boxed in - something else has to move, and the cheapest something else
is a trace that has not been routed yet. Placing the via first turns it
inside out: the via becomes copper the signal nets route AROUND.

Measured on this placement, sweeping twelve route orders each way:

| | best result | pour failures |
|---|---|---|
| repair afterwards | 1 stranded ground pad | **12 of 12** route orders |
| fan out first | 1 unrouted net | **0 of 12** |
| fan out first, production rip-up | **0** | 0 |

It is a real trade and it was not obviously going to pay: 24 through-hole
vias each block 4.4 units on all four layers, so ground buys its
connection with routing room the signal nets were using. What makes it
worth taking is not the raw count but the KIND of failure left over. A
pour pocket is made by the placement and no route order touches it; an
unrouted net is what route order fixes, repeatedly and by a lot.

**And the via has to be judged by real geometry.** `via_ok()` reads the
ROUTER's occupancy grid, which carries dilated keepout rings sized so a
TRACE has room for its own half-width, plus `contested` wherever two nets'
rings merely overlap. Between two SOIC pads nearly every cell is
contested, so it refuses a via that has 2.9x the clearance it needs:

```
via centred on a SOIC ground pad
  neighbour pad edge  3.75 units from the pad centre
  via pad edge        1.40
  real gap            2.35 units (0.597 mm) vs CLEAR 0.80 - LEGAL
```

`pad_plane_via()` therefore checks the same exact geometry `verify()` uses
plus the real drill rules, and ignores `occ` entirely. That fix alone took
stranded pads from five to two before fanout existed. It is the same
lesson as "do not model the pour from `occ`", one level up: `occ` is the
router's own conservative bookkeeping and it is not a clearance rule.

The checks are:

* **Clearance** — every pair of copper features (pad, track segment, via) that
  shares a layer and belongs to different nets, by exact geometric distance,
  using each net's *actual* trace width (12 mil signal, 16 mil power/ground -
  see "Trace widths" below). Must be ≥ 8 mil. JLCPCB's limit is 5 mil, so
  there is margin.
* **Connectivity** — union-find over touching same-net features, vias linking
  layers. Every pad of a net must end up in one piece.
* **Schematic agreement** — the pad set must equal the schematic pin set, both
  directions.
* **Mounting holes** — nothing may sit within 8 mil of an M3 hole.
* **Board edge** — every pad inside the outline, and no copper within 0.5 mm
  of it.
* **Wasted area** — the board is gridded and the largest all-empty rectangle
  found, arithmetically. Utilisation is reported every run, and a single void
  over 10 % of the board is an error. This is the "why is there a big empty
  patch" question answered by measurement instead of by squinting at a preview.
* **Silkscreen** — no silk over an exposed pad (the fab clips it), none over a
  top-layer trace or via, none running off the board edge.
* **Footprint courtyards** — every pair of placed components' bounding boxes
  (pads *and* silkscreen label, not just pads) must not overlap. Copper
  clearance alone only catches an overlap if two parts' pads happen to collide
  too; this catches two component *bodies* sitting on top of each other even
  when their copper never touches.

These caught real defects during development that would have reached the fab
otherwise: vias placed too close to foreign copper (a via is wider than the
track that leads to it, so a cell that is safe for a track is not automatically
safe for a via); an occupancy grid that recorded only the first net to claim a
cell, letting a second net route into the same keep-out; two test-point pads
sitting on top of mounting holes; the parallel tuning caps carrying an 0805
footprint when they are 1210 parts; tracks routed straight through the pot
locating holes; when the pots were added, eight nets left unrouted and three
left in disconnected pieces; when trace widths were first split by purpose,
pad keepouts that had been sized from the *pad's own* net rather than
from the widest trace that might pass nearby - backwards, and the cause of
every clearance violation that turned up while that version was in place; and,
once the footprint-courtyard check existed at all, two adjacent 1210 tuning
caps that had been overlapping by 0.6 units even before this round of changes
started - the 1210 footprint (18.6 units with clearance) is wider than the
18-unit placement-grid pitch, and nothing before this check compared two
components' *bodies* against each other, only their copper. Fixed by making
placement itself collision-aware (checking real per-part boxes as it assigns
slots) instead of just widening the grid pitch for every part, which would
have wasted area on every 0805 that didn't need it.
Not one of those was visible in the preview image.

## The stackup

Four layers, JLCPCB's standard 1.6 mm 4-layer build:

| | | |
|---|---|---|
| **L1** | TopLayer | signal, every SMD pad, GND pour |
| **L2** | Inner1 | **solid GND plane** - nothing is ever routed here |
| **L3** | Inner2 | signal |
| **L4** | BottomLayer | signal, GND pour |

Three signal layers and one uninterrupted ground: the standard analogue
4-layer arrangement.

**Why it is four and not two.** Two layers ran out. Once the three panel
mute buttons went into the front row, ~115 placement seeds and
route-order sweeps could not produce a board that verified - eight nets
left in pieces, both supply rails among them - on a board only 54%
utilised. Running out of copper at 54% is the signature of running out of
CHANNELS rather than of area, and the lever for that is layers. Finer
design rules were measured first and were worse (`CLEAR=0.6` scored 106
DRC problems against 54), because `CLEAR` feeds the placer's own cost
model as well as the router's rule: turn it down and the placer believes
escapes are cheaper than they are and packs tighter.

**What the plane buys, beyond capacity.** GND stops depending on a pour
threading its way between pads on a signal layer. Every ground pad now
reaches the plane straight down through a via, and a via ties all four
layers because JLCPCB's standard process has no blind or buried ones.
"The ground pour does not reach N pad(s)" - the single most common reason
a board in this project failed to verify - largely stops being a category
of failure.

**Vias.** All through-hole, 0.6 mm drill / 0.71 mm pad as before. Each one
punches an antipad in the plane, which the pour cuts automatically at
`POUR_CLEAR`; the router does not model the plane at all, which is
deliberate - see `PLANE_L` in `tools/gen_pcb_smd.py`.

**Building the two-layer version.** `LAYERS=2 python3 tools/gen_pcb_smd.py`
still works and is what every measurement in this file dated before the
stackup change was taken on. It will not route this board clean.

**Cost.** A 4-layer order is dearer than 2-layer at the same size - that
is the trade, and it is the only thing 4 layers costs here. Every
geometric limit `validate_fab.py` checks is the same or looser on the
4-layer process.

## Trace widths

Every trace used to be the same 8 mil regardless of what it carried. Widths are
now matched to purpose:

| | Width | Carries |
|---|---|---|
| Signal | 12 mil | A few mA at most - the crossover's actual audio signal |
| +15V, -15V, GND | 16 mil | The combined supply current of both quad op-amps, and (GND) the audio return path |

**Current capacity was never the constraint at any width considered**, and
that's worth being explicit about rather than implying otherwise. By
IPC-2221's external-layer formula for 1 oz copper,
`I = 0.048 · ΔT^0.44 · (w[mil] · 1.378)^0.725` at a conservative 10°C rise:

| Width | Capacity | vs. ~58 mA worst case (both op-amps, loaded) |
|---|---|---|
| 8 mil (the original, one-size-fits-all trace) | ~750 mA | ~13× |
| 12 mil (current signal) | ~1.0 A | ~17× |
| 16 mil (current power/ground) | ~1.25 A | ~21× |

So why not stay at 8 mil and save the board area? Because a trace
noticeably thinner than its pad reads as a mistake, not a design choice, on
a board this densely packed with fat hand-solder-friendly pads. 12/16 mil
puts signal traces at roughly 1:3.3 and power traces at roughly 1:2.5 against
an 0805 pad's 40 mil short dimension - inside the range of thumb that PCB
layout guides commonly cite for a trace that looks intentional rather than
broken (e.g. the general routing-technique discussions at
[aivon.com](https://www.aivon.com/blog/pcb-design/pcb-routing-techniques-a-comprehensive-guide-to-efficient-trace-layout/)
and [allpcb.com](https://www.allpcb.com/allelectrohub/pcb-layout-considerations-and-best-practices)
— unaudited sources, cross-checked here only against the IPC-2221 numbers
above, which is the part that actually matters). The wider traces cost some
board area, but the courtyard fix and the rotation-aware placement search
below (which shrank the board on their own) more than paid for it - the
final board is *smaller* than the 76.2 × 50.8 mm version that used thinner
traces, not larger.

Getting this correct (not just wider) took two real fixes, both caught by the
clearance check rather than assumed:

* **Pad keepouts had to stop depending on the pad's own net.** A pad's
  clearance requirement is about what might route *past* it, which has nothing
  to do with what net the pad itself is on - the first version reserved room
  based on the pad's own net, which under-reserved every signal pad by exactly
  the signal/power width difference. IC pads were then kept as a deliberate
  exception - own-net-based and skipping the grid margin - on the reasoning
  that a 16 mil trace could not fit between two SOIC pins anyway. That
  exception has since been removed, because both halves of it were wrong:
  the inter-pin channel needs 2.8 units and has 2.5, so nothing legal ever
  fit there, and the exception applied to the pad's *whole perimeter*, not
  just the gap between pins, leaving a trace running past an IC pin sitting
  exactly on the clearance limit with nothing spare for 45° chamfering to
  eat. Every layout the placement search produced tripped it at 7.4-7.8 mil
  against an 8 mil rule; the hand-placed board escaped only because no trace
  happened to take that route.
* **A wide net can't trust a tight keepout it didn't create.** Pathfinding for
  +15V/-15V/GND checks a widened neighbourhood, not just the literal cell, so
  it can't hug a pad reservation that was sized for a thinner trace. That
  neighbourhood is precomputed once per net (a single vectorised dilation) and
  reused for every cell A* visits, rather than recomputed per cell - the first
  version did the recompute-per-cell version, which was correct but took
  several minutes instead of the ~30 seconds a run takes now.

## Corner routing

The router is a strict 4-directional grid A* (see `astar()`/`emit_path()` in
`tools/gen_pcb_smd.py`) - every trace it produces is pure right-angle
Manhattan routing. 90° corners are legal and JLCPCB will happily fab them,
but sharp right-angle traces are widely flagged in PCB layout guides as
worth avoiding where free: historically an acid-trap risk during etch, and
even where that no longer applies (as here) a 90° corner still reads as
unfinished/auto-routed rather than hand-checked (see the general layout
discussions cited above, and e.g.
[tinycomputers.io](https://tinycomputers.io/posts/the-mathematics-of-pcb-trace-routing.html)
on routing geometry - again, unaudited, used only for the general practice,
not for any specific numeric claim).

Rather than rewrite the router itself to search in 8 directions (a much
larger change, with its own diagonal-clearance and diagonal-via rules to get
right), every routed polyline gets a post-process **chamfer**: each interior
90° corner is cut back by 15 mil along both legs and replaced with a short
45° diagonal. Endpoints - which land exactly on a pad or via - are never
touched.

This is safe by construction, not just by inspection: every point stamped
while routing already carries `CLEAR + MAX_W/2 + GRID` = 1.85 units of margin
beyond its own half-width, reserved so that *later* nets treat it as
occupied. A 15 mil chamfer deviates from the original corner by at most
`15 mil / √2 ≈ 10.6 mil`, comfortably inside that reserved margin - so the
cut can never intrude on a net that routed afterward and stayed clear of the
original right-angle corner. The independent geometric verifier checks the
*actual* chamfered geometry (not the router's pre-chamfer path), and the
board still comes back with zero clearance or connectivity problems after
chamfering every corner.

## Vias

0.20 mm annular ring (2.8 mm pad, 1.2 mm drill) - bumped up from an earlier
0.15 mm, which an independent DFM review flagged as leaving essentially no
margin against ordinary drill-to-pad registration tolerance at a
fabricator. 0.20 mm is comfortably inside JLCPCB's process capability.

### Ground stitching

Ground is poured on all four layers - solid on Inner1 - and every
through-hole part - the five
pots and all five terminal blocks - ties those two pours together for free
simply by being a plated hole. The SMD-only ground connections don't get
that: `R1`, `R3` and `R13` (the input bias return and the two Q-setting
resistors) would otherwise reach the opposite pour only through whatever
via a stub happened to need.

Each of those now gets a **deliberate second via placed right beside it**,
after all routing (including retries) is finished. It matters most at
`R1`, the input stage's ground reference, where the signal is at its
smallest and has no gain ahead of it to swamp any hum picked up across a
higher-impedance ground path.

Each candidate position is checked with the same strict `via_ok()` the
router itself uses, and the first of four offsets that passes is taken, so
a spot that would actually crowd existing copper is skipped rather than
forced. Cheap insurance: 5 GND vias on the current board, no measurable
cost in area or routing.

## Silkscreen over copper

No label may sit over a top-layer trace or via, enforced by construction: every
top-silk label's bounding box is stamped as a routing keepout *before* routing
starts, on the top copper layer only (bottom copper is the other side of the
board, so it can't visually clash with top silk). One deliberate exception -
a designator sitting right beside its own part's pads is allowed to displace
that part's own keepout *ring* (never the pad's literal footprint), since
nothing has been routed yet at that point and forcing the trace out just makes
it leave the pad in a slightly different direction.

## Parts

**The parts table is generated: [`parts.md`](parts.md).** Every line, both
the 69 machine-assembled footprints and the 17 you solder yourself, comes
out of the BOM the fab is actually sent, so it cannot drift from the board.

It used to be a hand-written table here, and it rotted exactly as you would
expect. It still listed two MC33079 after the output buffers added a third,
`C5`–`C8` after the third package added `C9`/`C10`, and a single 10 µF
designator after six more appeared — next to a part number that had since
gone end-of-life. That is the same "hand-maintained second copy" this
project already refuses to keep for footprint geometry, and it failed the
same way.

What stays here is the part of it a generator cannot write:

**Extended vs basic.** JLCPCB charges a one-off fee per *extended* part
type, so the count matters more than the quantity. Two of them are
avoidable if you care: **`R3`/`R13` could be 12k** (basic, C17444) at a cost
of 0.14 dB in the summed response. **`R17`/`R18` cannot** — 12k would push
filter 2's top end to 201 Hz, above filter 1's 195 Hz minimum, which
re-creates the range overlap the retune existed to remove.

**The thinnest line is the 33 nF.** `C569866` runs a couple of thousand in
stock against six per board — about 330 boards' worth, fine for a build and
worth checking before a batch. It is also the one part where a substitution
is least welcome: see the next section.

**Stock figures drift.** `python3 tools/validate_fab.py --online` queries
the live numbers, and now *fails* rather than warns if a part number no
longer resolves at all.

### Why the tuning caps are two 33nF in parallel

C3 and C4 want 68nF. At 50 V, in a film or C0G dielectric, 68nF is not stocked:
the PPS part exists only at 16 V (too close to the ±15 V rails) and C0G at that
value is scarce, expensive and ±10%. Two 33nF ±2% PPS in parallel give 66nF —
which with R17/R18 = 13k puts filter 2 at **73–186 Hz**, against the 71–180 Hz
of the through-hole build.

This is better than the alternative rather than a compromise. Every tuning
capacitor on the board is now the same part from the same reel, and **matching
between C1/C2 and between C3/C4 is the tightest tolerance that matters in this
circuit** — a 10% mismatch costs 0.41 dB. Ordinary X7R would have been cheap and
available, and wrong: its voltage coefficient puts distortion in the signal
path, which is exactly what this design is otherwise careful to avoid.

## Ordering

1. Import the PCB into EasyEDA Std: **File → Open → EasyEDA…**
2. **Look at it.** Run **Design → Design Rule Check** with JLCPCB's rules.
3. **Export the Gerbers from EasyEDA**, and **export the BOM and CPL from
   EasyEDA too** — not the CSVs in this repo.

   `bom/jlcpcb-bom-retuned-quad-smd.csv` is reliable (it is just value,
   designator, footprint, part number). `bom/jlcpcb-cpl-retuned-quad-smd.csv`
   is **reference only**: a CPL's coordinates are relative to whatever origin
   the Gerbers were generated with, and only EasyEDA knows that at export time.
   Using the wrong origin puts every part in the wrong place.
4. Upload to JLCPCB, choose assembly, and check the rendered preview before
   paying — the preview shows part orientation, which is the usual failure mode.

## The two rows, and the margin outside them

**Rear row, left to right: `J2` line in, `J5` LOW, `J4` MID, `J3` HIGH,
`J1` power.** The three outputs are adjacent and in the panel's own order.
They used to be split by the power block (in, LOW, power, MID, HIGH),
which put mains-side wiring in the middle of the audio-side wiring and made
three amplifier looms fan out around it. Power now sits at the far end from
the input — the one signal with no gain in front of it.

**Nothing is outboard of a mounting screw.** The left and right margins are
wider than the front and rear ones (`EDGE_X`), sized so a hole fits beyond
the outermost part: `CLEAR + 2·MOUNT_R + MOUNT_EDGE_MIN`. That strip is
therefore empty by construction, so the corner holes cannot collide with
anything and only ever walk in Y — and `verify()` asserts the result rather
than trusting it.

It was not always so: the holes used to walk *inward* to clear the panel
row, which left `VR6` cantilevered 10.7 mm past the bottom-left screw. The
master volume is the control most likely to be leaned on.

## The potentiometers

**VR1 and VR2 sit on the board**, on the front edge, on the same 80-unit
knob pitch that spaces every KNOB on the board, VR1/VR2 included (see
"Output volume control" below); it grew from an earlier, VR1/VR2-only
spacing of 110 units when the volume trims needed real pitch of their own,
and the row is no longer uniform now that the mute buttons are in it (see
"The mute buttons"). The board
lies flat in the enclosure, **perpendicular to the front panel**, with
right-angle pots on the front edge and their shafts through the panel -
the arrangement a small amplifier or preamp board normally uses. Every
control in the row is an edge-mount part for that reason, the mute buttons
included.

The footprint is the near-universal **9 mm dual-gang pattern**: six terminals in
two rows of three. Real parts
are on 5.00 mm centres and this footprint is on 5.08 mm (0.2 in), because pad
centres must land on the routing grid; the 0.08 mm per pitch is absorbed by the
1.2 mm holes.

**There are no locating-boss holes.** There used to be two, at a position
that was openly a guess: no verified dual-gang mechanical drawing was ever
found for this part, and LCSC's footprint API - the one this file
documents using - now answers `403` from CloudFront, so there is no longer
a way from here to turn the guess into a measurement. Between shipping an
unverified hole and shipping none, none is strictly the safer default: a
missing hole is two minutes with a hand drill against your own part's
datasheet, and a hole in the wrong place is a re-order. The pots solder in
through six pins and sit against the panel; the bosses locate, they do not
carry load.

> **Verify this against your pot's datasheet before ordering.** LCSC stocks
> RK09-family 20 k parts (e.g. C470290, ~1200 in stock) but the API does not
> expose gang count or mechanical dimensions, so this footprint is drawn from the
> standard pattern rather than from a specific verified part. It is a
> parametrised function in `tools/gen_pcb_smd.py` — easy to correct.

JLCPCB will not assemble the pots; solder them yourself, along with the
connectors and test points.

## Output volume control

**Each output (VR3 HIGH, VR4 MID, VR5 LOW) gets its own single-gang 10 kΩ
audio-taper pot**, wired as an attenuator between that band's filter output
and its terminal block - not part of the filter, and not touching the
filter's own gain-setting resistors. Electrically this is a plain voltage
divider: the filter's op-amp output already drives a low impedance, so it
can source a 10 kΩ pot with no measurable effect on the filter response,
and since a divider only ever attenuates, it introduces no new clipping
risk.

Audio taper (log), not linear, because this panel is meant to work as the
system's actual volume control per band, adjusted by ear - a linear pot
feels bunched up, with most of the audible change crammed into the last
10-20° of rotation.

Part: **Alps Alpine RK097111080R, LCSC C470577** - 10 kΩ, taper code `15A`
(audio/log per Alps' own product page), single-turn, 3-terminal through
hole, 826 in stock at lookup. The AliExpress "RK097N" listing this was
sourced from is a rebrand of the same genuine Alps series (same model
family, same spec sheet), which is why it was worth chasing down a real
LCSC part rather than parametrising a guess: unlike VR1/VR2's dual-gang
footprint, this one has a verified EasyEDA pinout+footprint behind it.
**Still worth a stock/spec re-check before ordering** - taper especially,
since neither the LCSC nor the JLCPCB parts API exposes it directly; it
came from Alps' own product page for this exact part number.

**Pad geometry is pulled from that real footprint, not guessed**: 2.5 mm
pin pitch (drawn on 2.54 mm, the nearest 0.5-unit grid point - absorbing
the same kind of sub-0.1 mm slop the dual-gang footprint already does
between its 5.00 mm real pitch and its 5.08 mm drawn one), ~1.9 mm pads,
~1.2 mm holes, all read directly from LCSC/EasyEDA's own PCB-layer SVG for
C470577 (`/api/products/C470577/svgs`). The first version of this
footprint just reused the dual-gang pattern's 5.08 mm pitch without
checking it against this specific part - about 2x too wide, and the reason
a rendered preview of it looked barely different from VR1/VR2. The ~9 mm
body/knob-collar circle is still a sketch from the AliExpress listing's
stated dimensions, not the same verified source - reasonable for a
courtyard, not a certified mechanical drawing.

Panel layout, left to right:

**MASTER (VR6) - [MUTE LO (SW3)] LOW VOL (VR5) - MID/LOW (VR2) -
[MUTE MID (SW2)] MID VOL (VR4) - HIGH/MID (VR1) - [MUTE HI (SW1)]
HIGH VOL (VR3)**

Nine controls: each volume trim flanks the frequency pot for the band it's
nearest, and each mute button sits immediately left of the volume trim it
mutes, so the two controls for a band read as a pair.

Two pitches, because two different things set them. Knob to knob is
`PANEL_PITCH`, 80 units (20.3 mm) - a knob for a 6 mm shaft is 15-20 mm
across, so much less has adjacent knobs touching. Knob to button is
`SWITCH_PITCH`, 56 units (14.2 mm), which leaves `2 x 14.2 - 18 = 10.4 mm`
of finger room between the two knobs a button sits between. Neither number
can be left to the optimiser: the courtyards would allow 58 and 34 units
respectively, and the optimiser has no model of a fingertip.

Every pot footprint, single- or dual-gang, has the same 26-unit body
half-width, so the shared knob pitch is what actually determines spacing -
see "Routing more controls" below for what happened when the first attempt
reused VR1/VR2's old, tighter spacing instead.

The row is also lined up on its **courtyard fronts**, not its pad rows: the
switch's mounting-lug pads reach ~0.8 mm further forward than a pot's body
does, and it is the board edge, not the pad row, that has to be one
straight line for the panel to sit flat against every control at once.
`PANEL_Y` computes the offsets from the probed geometry, so a footprint
change carries through instead of quietly leaving one control short.

## Two pinned edge rows

Everything that has to reach an edge is pinned into one of **two rigid
rows**, and they go down before anything else is placed:

* the **panel row** on the front edge - nine controls, `PANEL_X`/`PANEL_Y`
* the **rear row** on the opposite edge - `J2` (IN), `J5` (LOW), `J1`
  (power), `J4` (MID), `J3` (HIGH), on `REAR_X`/`REAR_Y`

The x of each rear part is borrowed from the panel row, so the two line
up: `J2` above MASTER (the input feeds the master volume, so that is the
short net), each output above the volume pot that feeds it, and `J1` in
the largest gap left - mid-board, the shortest average distance from the
power terminal to the three ICs and a long way from the input. Each row is
aligned on the parts' outer FACES, not their pad rows, so the row presents
one flat plane to its edge.

**Why pin them at all.** Their positions were never really a search
problem - a pot has to be at the panel and a screw terminal has to be at an
edge - and leaving them free produced exactly what you would expect: `J2`,
the input, ended up in the bottom-left corner facing across the board, on
the same edge as the panel. `place.seed()` skips grouped parts, so pinning
a row also means everything else gets seeded *around* it rather than the
row having to fight into a board that is already full.

**And a row defines a plane.** `edge_violation()` checks a rigid row as
one wide part against its own outer face, with no column test; a lone
edge-facing part is still checked per column (see the docstring for why
the two cases differ). Per-column alone was not enough and the board showed
how: `PANEL_PITCH` leaves 41 units of clear gap between one knob and the
next, part of no column, and the anneal happily parked C5/C6/R2/R4 in
*front* of the pot row - where the front panel has to go.

The weight is `W_EDGE`, and unlike the other placement weights it is priced
to be **unpayable rather than traded**: it expresses a mechanical fact, not
a routability guess. At the old 40 the anneal parked `J6` 5.7 mm in front
of the panel row and paid 20k out of a 142k total to keep it near its
switch. At 400 the term reads zero.

Board size is still an OUTPUT. The rows are pinned in x and in their
row-relative y, but each row's absolute depth is free - it is a rigid
group, and the anneal slides the rear row in until the parts between the
two rows stop it. What is fixed is only that nothing may be outside either
row, so the board edges land `EDGE` (1.27 mm) behind each one.

`WIDTH_LOG=1` prints a `rows:` line naming anything that got outside a row
and by how much, because the board line only reports the total and a part
sticking out is invisible in it.

## The mute buttons

**SW1, SW2 and SW3 are on the board**, in the front-panel row, one beside
each band's volume trim. They are **G-Switch PS-22E05** (LCSC `C2848949`,
~£0.16, 925 in stock at the time of writing): a **right-angle push-lock
DPDT**, so the plunger comes out of the board edge in the same direction as
the pot shafts and goes through the same panel. That is the whole reason
for this part: the board sits flat in the enclosure, perpendicular to the
front panel, so every control has to be an edge-mount one.

The footprint is drawn from G-Switch's own outline drawing (PS-22E05
rev X1, 2016-05-29), P.C.B LAYOUT / BOTTOM VIEW panel - not from another
footprint, and not from a listing's stated dimensions:

| | |
|---|---|
| signal pins | 6, 0.8 mm holes, 2 x 3 on a 2.5 mm grid |
| mounting lugs | 2, 1.3 mm holes, 4.0 mm across x 11.4 mm along, diagonally opposite |
| body | 12.0 x 6.6 mm, 11.9 mm tall |
| plunger | 10.3 mm proud of the body at rest, 3.5 mm travel, 2.2 mm to latch |
| rating | 0.5 A 30 VDC, contact resistance <= 100 mOhm, 10,000 cycles |

Drawn on 2.54 mm rather than the datasheet's 2.5, the same sub-0.1 mm slop
`fp_pot_single` already absorbs: 0.08 mm accumulated across the pin field
against a 0.86 mm hole on a 0.5 x 0.6 mm pin.

**Three things about this part are taken on trust and should be checked
with a meter on one switch before ordering.**

1. **Which throw closes when it latches.** The drawing shows the two poles
   and the non-shorting changeover but never says which end the common
   latches onto, and no distributor page does either. The generator
   assumes the end away from the plunger. `MUTE_SW_SENSE=beta` swaps it -
   both spare throws are drilled and plated either way, so being wrong is
   a regenerate rather than a rework.
2. **Whether the frame lugs are isolated from the contacts.** The board
   solders them to GND, because they take the push force and a dry lug on
   a switch you press is a joint that eventually cracks. Every switch of
   this construction has an isolated frame; the drawing does not say so.
3. **That it is the LOCK variant.** The family part number is PS-22E05XX
   where the suffix carries N = no lock, L = lock (and a cap colour). LCSC
   lists `C2848949` as plain "PS-22E05" under its self-locking category,
   which is the reason for believing it latches.

The LED pole is wired so none of this matters to the indicators: it is
taken from the throw at the *opposite* end from the mute ground, so
whichever way the mechanism goes, the LED is lit exactly when its band is
not muted. See `docs/circuit-notes.md`.

**Pitch is set by fingers, not by copper.** The panel row now has two
pitches - `PANEL_PITCH` (80 units, 20.3 mm) between knobs and
`SWITCH_PITCH` (56 units, 14.2 mm) between a knob and the button beside
it. The button's courtyard would allow 34 units, but what actually sets
the number is that `2 x 14.2 - 18 = 10.4 mm` of gap has to be left between
the two knobs a button sits between, for a fingertip. Using the knob pitch
for the buttons would have cost 30 mm of board and bought nothing.

JLCPCB will not assemble these; solder them yourself with the pots and
connectors.

## Not assembled

* **VR1, VR2** — the frequency pots (above).
* **VR3, VR4, VR5** — the per-band volume trims (above).
* **VR6** — the master volume, ahead of the input buffer.
* **SW1, SW2, SW3** — the mute buttons, in the panel row between the volume
  pots (above). Right-angle push-lock DPDTs, so the plunger comes out of the
  board edge alongside the pot shafts.
* **J6** — a 4-pin header for the optional panel LEDs. DC only; no audio
  leaves the board on it, and the mute switches no longer go through it.
* **J1** ±15 V and ground, **J2** input, and **J3 / J4 / J5** — one 2-way
  screw terminal block per output, each carrying its own signal *and its own
  ground return*, because each one runs to a separate power amplifier. Sharing
  a single ground pin between three amplifier feeds invites hum loops. All on
  the rear edge, opposite the controls, so the box wires up sensibly.
  Blocks are 3.5 mm pitch (drawn on 3.556 mm, absorbed by the 1.1 mm holes).
* **TP1, TP2** — the null test points, rear edge.
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

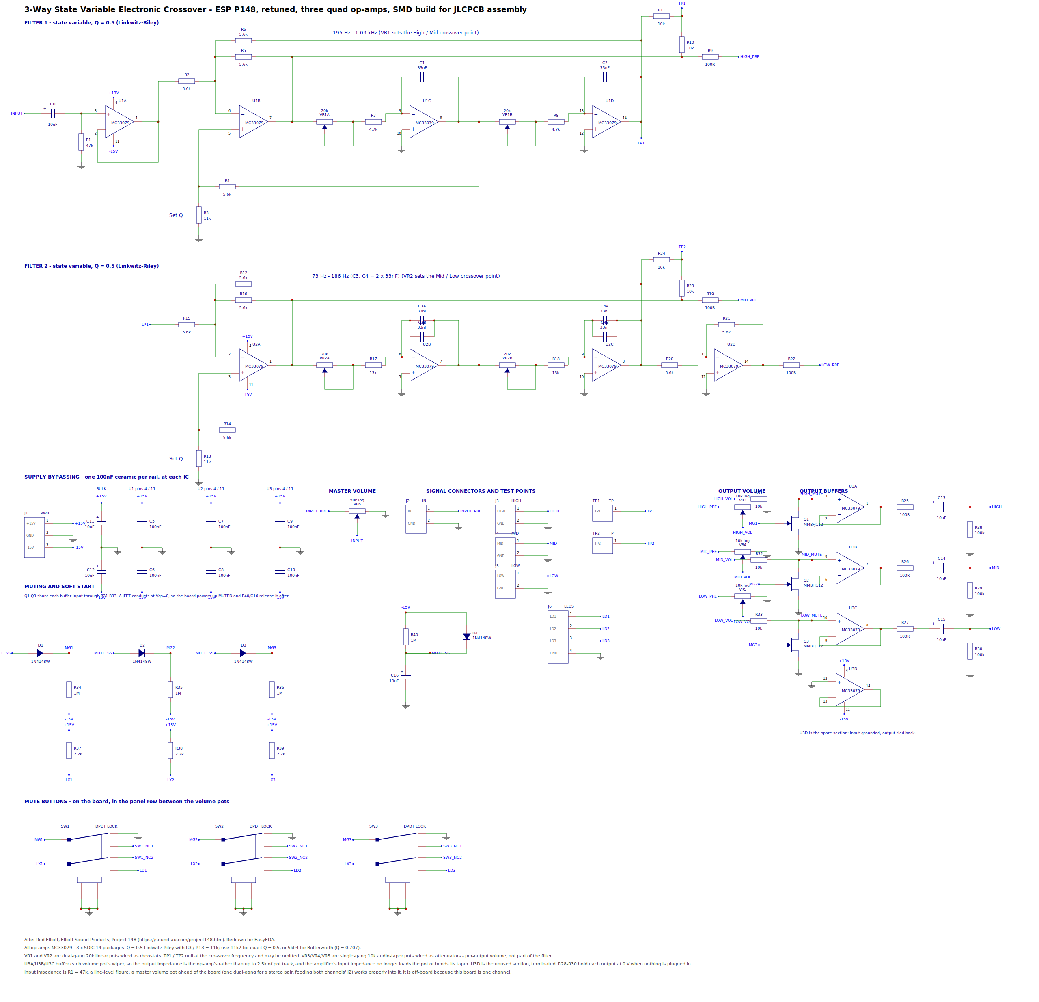
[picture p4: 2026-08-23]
schematic/esp-p148-3way-crossover-retuned-quad-smd.png

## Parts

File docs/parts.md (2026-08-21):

# Parts

Generated by `tools/gen_pcb_smd.py` from the BOM the fab is sent, so
it cannot drift from the board. Stock is the figure recorded when each
part was last looked up; `python3 tools/validate_fab.py --online`
queries the live number and **fails** if a part no longer resolves.

## Machine-assembled (69 of 86 footprints)

| Value | Designators | Package | LCSC | JLC library | Stock at lookup |
|---|---|---|---|---|---|
| 100nF | C5-C10 | 0805 | `C49678` | **basic** | 14 609 213 |
| 47k | R1 | 0805 | `C17713` | extended | 1 661 600 |
| 10k | R10, R11, R23, R24, R31-R33 | 0805 | `C17414` | **basic** | 34 645 450 |
| 5.6k | R2, R4-R6, R12, R14-R16, R20, R21 | 0805 | `C4382` | **basic** | 787 448 |
| 11k | R3, R13 | 0805 | `C17429` | extended | 78 383 |
| 13k | R17, R18 | 0805 | `C2933304` | extended | 213 066 |
| 100R | R9, R19, R22, R25-R27 | 0805 | `C17408` | **basic** | 7 430 702 |
| 100k | R28-R30 | 0805 | `C17407` | extended | 248 500 |
| 1M | R34-R36, R40 | 0805 | `C17514` | extended | 2 205 500 |
| 2.2k | R37-R39 | 0805 | `C17520` | extended | 3 197 400 |
| 4.7k | R7, R8 | 0805 | `C17673` | **basic** | 6 989 256 |
| 33nF | C1, C2, C3A, C3B, C4A, C4B | 1210 | `C569866` | extended | 2 001 |
| 10uF | C0, C11-C16 | CASE-D5xL5.4 | `C2858858` | extended | 50 240 |
| 1N4148W | D1-D4 | SOD-123 | `C22374707` | extended | 6 100 |
| MC33079 | U1-U3 | SOIC-14 | `C9376` | extended | 25 307 |
| MMBFJ112 | Q1-Q3 | SOT-23 | `C258195` | extended | 18 545 |

## Hand-soldered (17 footprints)

JLCPCB does not assemble through-hole parts. Every one of these is
edge or panel hardware, so none of it is fiddly.

| Designator | What it is | Value / package |
|---|---|---|
| `J1` | Power input, +15 V / GND / -15 V | TB-3P-3.5 |
| `J2` | Line input | TB-2P-3.5 |
| `J3` | HIGH output | TB-2P-3.5 |
| `J4` | MID output | TB-2P-3.5 |
| `J5` | LOW output | TB-2P-3.5 |
| `J6` | Panel-LED header (optional) | MUTE, HDR-1X4 |
| `SW1` | HIGH mute button | DPDT LOCK, SW-PS22E05 |
| `SW2` | MID mute button | DPDT LOCK, SW-PS22E05 |
| `SW3` | LOW mute button | DPDT LOCK, SW-PS22E05 |
| `TP1` | Test point, HIGH/MID null | THT-PAD |
| `TP2` | Test point, MID/LOW null | THT-PAD |
| `VR1` | HIGH/MID crossover frequency | 20k dual, POT-9MM-DUAL |
| `VR2` | MID/LOW crossover frequency | 20k dual, POT-9MM-DUAL |
| `VR3` | HIGH band volume | 10k log, POT-9MM-SINGLE |
| `VR4` | MID band volume | 10k log, POT-9MM-SINGLE |
| `VR5` | LOW band volume | 10k log, POT-9MM-SINGLE |
| `VR6` | Master volume | 50k log, POT-9MM-SINGLE |

Commentary - why the tuning capacitors are two 33 nF in parallel, and
which extended-library lines are worth avoiding - is in
[`pcb-notes-smd.md`](pcb-notes-smd.md#parts).

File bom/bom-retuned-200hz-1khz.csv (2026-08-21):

Qty | Value | Package | Designators | Notes
1 | 10uF | C_AXIAL-0.2 | C0
2 | 33nF | C_AXIAL-0.2 | C1, C2
2 | 68nF | C_AXIAL-0.2 | C3, C4
8 | 100nF | C_AXIAL-0.2 | C5, C6, C7, C8, C9, C10, C11, C12
8 | NE5532 | DIP-8 | U1A, U1B, U2A, U2B, U3A, U3B, U4A, U4B | 4 x dual op-amp packages (U1-U4); each drawn as two sections
4 | 20k | POT-9MM-DUAL | VR1A, VR1B, VR2A, VR2B | 2 x dual-gang 20k linear pots (VR1, VR2); wired as rheostats
1 | 47k | R_AXIAL-0.4 | R1 | Sets the board's input impedance - see docs/design-review.md
10 | 5.6k | R_AXIAL-0.4 | R2, R4, R5, R6, R12, R14, R15, R16, R20, R21
2 | 11k | R_AXIAL-0.4 | R3, R13 | Sets filter Q (0.503); 11k2 = exact Q 0.5, 5k04 = Butterworth
2 | 4.7k | R_AXIAL-0.4 | R7, R8
3 | 100R | R_AXIAL-0.4 | R9, R19, R22 | Build-out resistors: R9/R19/R22 from each filter into its volume pot, R25/R26/R27 from each output buffer into the interconnect
4 | 10k | R_AXIAL-0.4 | R10, R11, R23, R24 | R10/R11/R23/R24 are the TP1/TP2 null network - optional
2 | 13k | R_AXIAL-0.4 | R17, R18
1 | IN | TB-2P-5.08 | J2 | Signal input
1 | HIGH | TB-2P-5.08 | J3 | Output terminal block to the treble amplifier
1 | MID | TB-2P-5.08 | J4 | Output terminal block to the midrange amplifier
1 | LOW | TB-2P-5.08 | J5 | Output terminal block to the bass amplifier
1 | PWR | TB-3P-5.08 | J1
2 | TP | TESTPOINT | TP1, TP2 | Test points - optional, omit with R10/R11 and R23/R24

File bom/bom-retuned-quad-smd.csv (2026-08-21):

Qty | Value | Package | Designators | Notes
6 | 10uF | CASE-D5xL5.4 | C11, C12, C13, C14, C15, C16
1 | 10uF | C_AXIAL-0.2 | C0
6 | 33nF | C_AXIAL-0.2 | C1, C2, C3A, C3B, C4A, C4B
6 | 100nF | C_AXIAL-0.2 | C5, C6, C7, C8, C9, C10
1 | LEDS | HDR-1X4 | J6 | Optional panel indicators: LD1/LD2/LD3 are current-limited feeds that are live when the band is playing, so a bare LED from each to the GND pin is the whole loom
4 | 20k | POT-9MM-DUAL | VR1A, VR1B, VR2A, VR2B | 2 x dual-gang 20k linear pots (VR1, VR2); wired as rheostats
3 | 10k log | RK097-AUDIO-10K | VR3, VR4, VR5 | 3 x single-gang 10k audio/log-taper pots (VR3 HIGH, VR4 MID, VR5 LOW); wired as an attenuator between the filter output and its terminal block, not as a rheostat
1 | 50k log | RK097-AUDIO-50K | VR6 | 1 x single-gang 50k audio/log-taper pot (VR6 MASTER), ahead of the input buffer so it sets how hard the whole filter is driven, not just the output level
1 | 47k | R_AXIAL-0.4 | R1 | Sets the board's input impedance - see docs/design-review.md
10 | 5.6k | R_AXIAL-0.4 | R2, R4, R5, R6, R12, R14, R15, R16, R20, R21
2 | 11k | R_AXIAL-0.4 | R3, R13 | Sets filter Q (0.503); 11k2 = exact Q 0.5, 5k04 = Butterworth
2 | 4.7k | R_AXIAL-0.4 | R7, R8
6 | 100R | R_AXIAL-0.4 | R9, R19, R22, R25, R26, R27 | Build-out resistors: R9/R19/R22 from each filter into its volume pot, R25/R26/R27 from each output buffer into the interconnect
7 | 10k | R_AXIAL-0.4 | R10, R11, R23, R24, R31, R32, R33 | R10/R11/R23/R24 are the TP1/TP2 null network - optional
2 | 13k | R_AXIAL-0.4 | R17, R18
3 | 100k | R_AXIAL-0.4 | R28, R29, R30 | Output bleeders: hold each output at 0 V through its coupling capacitor when nothing is plugged into the terminal block
4 | 1M | R_AXIAL-0.4 | R34, R35, R36, R40
3 | 2.2k | R_AXIAL-0.4 | R37, R38, R39
4 | 1N4148W | SOD-123 | D1, D2, D3, D4
12 | MC33079 | SOIC-14 | U1A, U1B, U1C, U1D, U2A, U2B, U2C, U2D, U3A, U3B, U3C, U3D | Quad op-amp packages, each drawn as four sections: U1 = filter 1, U2 = filter 2, U3 = output buffers (U3D spare, terminated). Any standard quad pinout fits: OPA1644, OPA4134, LME49740, TL074 - and a FET-input one removes the bias-current offset R1 develops
3 | MMBFJ112 | SOT-23 | Q1, Q2, Q3
3 | DPDT LOCK | SW-PS22E05 | SW1, SW2, SW3 | G-Switch PS-22E05 (LCSC C2848949) right-angle push-lock DPDT, one per band, in the panel row. Pole A grounds the JFET gate; pole B switches that band's LED feed. Check the frame lugs are isolated from the contacts before ordering - the board grounds them
1 | IN | TB-2P-5.08 | J2 | Signal input
1 | HIGH | TB-2P-5.08 | J3 | Output terminal block to the treble amplifier
1 | MID | TB-2P-5.08 | J4 | Output terminal block to the midrange amplifier
1 | LOW | TB-2P-5.08 | J5 | Output terminal block to the bass amplifier
1 | PWR | TB-3P-5.08 | J1
2 | TP | TESTPOINT | TP1, TP2 | Test points - optional, omit with R10/R11 and R23/R24

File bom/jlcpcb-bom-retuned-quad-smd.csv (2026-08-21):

Comment | Designator | Footprint | LCSC Part # | JLC Library
100nF | C5,C6,C7,C8,C9,C10 | 0805 | C49678 | basic
47k | R1 | 0805 | C17713 | extended
10k | R10,R11,R23,R24,R31,R32,R33 | 0805 | C17414 | basic
5.6k | R2,R4,R5,R6,R12,R14,R15,R16,R20,R21 | 0805 | C4382 | basic
11k | R3,R13 | 0805 | C17429 | extended
13k | R17,R18 | 0805 | C2933304 | extended
100R | R9,R19,R22,R25,R26,R27 | 0805 | C17408 | basic
100k | R28,R29,R30 | 0805 | C17407 | extended
1M | R34,R35,R36,R40 | 0805 | C17514 | extended
2.2k | R37,R38,R39 | 0805 | C17520 | extended
4.7k | R7,R8 | 0805 | C17673 | basic
33nF | C1,C2,C3A,C3B,C4A,C4B | 1210 | C569866 | extended
10uF | C0,C11,C12,C13,C14,C15,C16 | CASE-D5xL5.4 | C2858858 | extended
1N4148W | D1,D2,D3,D4 | SOD-123 | C22374707 | extended
MC33079 | U1,U2,U3 | SOIC-14 | C9376 | extended
MMBFJ112 | Q1,Q2,Q3 | SOT-23 | C258195 | extended

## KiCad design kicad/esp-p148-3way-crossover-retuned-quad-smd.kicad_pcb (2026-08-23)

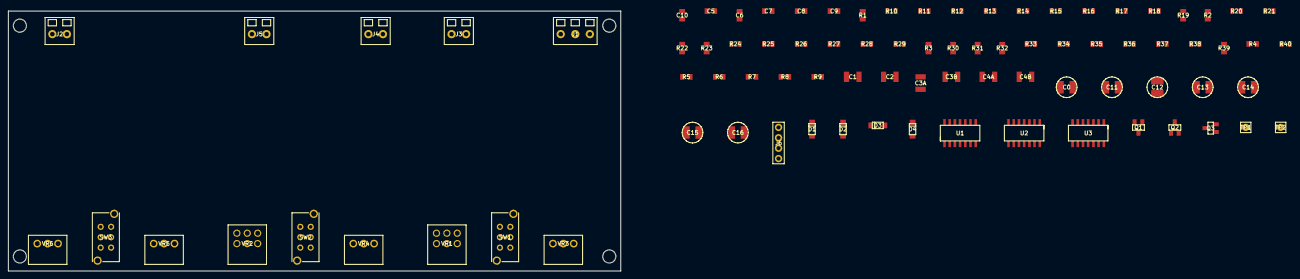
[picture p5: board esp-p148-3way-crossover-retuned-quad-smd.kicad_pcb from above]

Board: 4 copper layers, 149.6 x 63.5 mm, 90 parts (0 on the bottom side), 58 nets, no tracks yet.

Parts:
C0, C11, C12, C13, C14, C15, C16: 10uF; CASE-D5xL5.4
C1, C2, C3A, C3B, C4A, C4B: 33nF; 1210
C5, C6, C7, C8, C9, C10: 100nF; 0805
D1, D2, D3, D4: 1N4148W; SOD-123
H1, H2, H3, H4: MountingHole
J1: TB-3P-3.5
J2, J3, J4, J5: TB-2P-3.5
J6: MUTE; HDR-1X4
Q1, Q2, Q3: MMBFJ112; SOT-23
R1: 47k; 0805
R2, R4, R5, R6, R12, R14, R15, R16, R20, R21: 5.6k; 0805
R3, R13: 11k; 0805
R7, R8: 4.7k; 0805
R9, R19, R22, R25, R26, R27: 100R; 0805
R10, R11, R23, R24, R31, R32, R33: 10k; 0805
R17, R18: 13k; 0805
R28, R29, R30: 100k; 0805
R34, R35, R36, R40: 1M; 0805
R37, R38, R39: 2.2k; 0805
SW1, SW2, SW3: DPDT LOCK; SW-PS22E05
TP1: TP1; THT-PAD
TP2: TP2; THT-PAD
U1, U2, U3: MC33079; SOIC-14
VR1, VR2: 20k dual; POT-9MM-DUAL
VR3, VR4, VR5: 10k log; POT-9MM-SINGLE
VR6: 50k log; POT-9MM-SINGLE

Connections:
+15V: C5.1, C7.1, C9.1, C11.1, J1.1, R37.1, R38.1, R39.1, U1.4, U2.4, U3.4
-15V: C6.2, C8.2, C10.2, C12.2, D4.1, J1.3, R34.2, R35.2, R36.2, R40.1, U1.11, U2.11, U3.11
GND: C5.2, C6.1, C7.2, C8.1, C9.2, C10.1, C11.2, C12.1, C16.2, J1.2, J2.2, J3.2, J4.2, J5.2, J6.4, Q1.2, Q2.2, Q3.2, R1.2, R3.2, R13.2, R28.2, R29.2, R30.2, SW1.1, SW1.7, SW1.8, SW2.1, SW2.7, SW2.8, SW3.1, SW3.7, SW3.8, U1.10, U1.12, U2.5, U2.10, U2.12, U3.12, VR3.3, VR4.3, VR5.3, VR6.3
HIGH: C13.2, J3.1, R28.1
HIGH_MUTE: Q1.1, R31.2, U3.3
HIGH_PRE: R9.2, VR3.1
HIGH_VOL: R31.1, VR3.2
INPUT: C0.1, VR6.2
INPUT_PRE: J2.1, VR6.1
LD1: J6.1, SW1.6
LD2: J6.2, SW2.6
LD3: J6.3, SW3.6
LOW: C15.2, J5.1, R30.1
LOW_MUTE: Q3.1, R33.2, U3.10
LOW_PRE: R22.2, VR5.1
LOW_VOL: R33.1, VR5.2
LP1: C2.2, R6.2, R11.1, R15.1, U1.14
LX1: R37.2, SW1.3
LX2: R38.2, SW2.3
LX3: R39.2, SW3.3
MG1: D1.2, Q1.3, R34.1, SW1.4
MG2: D2.2, Q2.3, R35.1, SW2.4
MG3: D3.2, Q3.3, R36.1, SW3.4
MID: C14.2, J4.1, R29.1
MID_MUTE: Q2.1, R32.2, U3.5
MID_PRE: R19.2, VR4.1
MID_VOL: R32.1, VR4.2
MUTE_SS: C16.1, D1.1, D2.1, D3.1, D4.2, R40.2
N160_280: C0.2, R1.1, U1.3
N350_300: R2.1, U1.1, U1.2
N530_100: R2.2, R5.1, R6.1, U1.6
N530_700: R12.1, R15.2, R16.1, U2.2
N570_320: R3.1, R4.1, U1.5
N570_920: R13.1, R14.1, U2.3
N680_300: R5.2, R9.1, R10.2, U1.7, VR1.1
N680_900: R16.2, R19.1, R23.2, U2.1, VR2.1
N830_300: R7.1, VR1.2, VR1.3
N830_900: R17.1, VR2.2, VR2.3
N950_300: C1.1, R7.2, U1.9
N950_900: C3A.1, C3B.1, R17.2, U2.6
N1100_300: C1.2, R4.2, U1.8, VR1.1
N1100_900: C3A.2, C3B.2, R14.2, U2.7, VR2.1
N1280_300: R8.1, VR1.2, VR1.3
N1280_900: R18.1, VR2.2, VR2.3
N1400_300: C2.1, R8.2, U1.13
N1400_900: C4A.1, C4B.1, R18.2, U2.9
N1580_640: C4A.2, C4B.2, R12.2, R20.1, R24.1, U2.8
N1680_900: R20.2, R21.1, U2.13
N1850_900: R21.2, R22.1, U2.14
N2150_1250: R25.1, U3.1, U3.2
N2150_1400: R26.1, U3.6, U3.7
N2150_1550: R27.1, U3.8, U3.9
N2150_1700: U3.13, U3.14
N2260_1250: C13.1, R25.2
N2260_1400: C14.1, R26.2
N2260_1550: C15.1, R27.2
TP1: R10.1, R11.2, TP1.1
TP2: R23.1, R24.2, TP2.1

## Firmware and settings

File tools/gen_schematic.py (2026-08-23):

#!/usr/bin/env python3
"""
Generate an EasyEDA (Std) importable schematic for the ESP Project 148
3-way State Variable Electronic Crossover.

Reference: https://sound-au.com/project148.htm  (Rod Elliott, ESP)

Outputs (into ../schematic and ../docs relative to this file):
  esp-p148-3way-state-variable-crossover.json        EasyEDA Std schematic (v6 head)
  esp-p148-3way-state-variable-crossover.legacy.json same shapes, legacy string head
  preview.svg / preview.png                          rendering of the same shape data
  netlist.txt                                        netlist extracted back out of the geometry

The schematic is described declaratively (components + orthogonal wire runs on a
10 px grid).  Junction dots are derived automatically, and the netlist is
re-extracted from the finished geometry so the drawing can be checked against the
intended connections rather than trusted blindly.
"""

import json
import os
import re

# --------------------------------------------------------------------------
# id allocation
# --------------------------------------------------------------------------
_next_id = [1]


def gid():
    _next_id[0] += 1
    return "gge%d" % _next_id[0]


WIRE_COLOR = "#008800"
PIN_COLOR = "#880000"
SYM_COLOR = "#000080"
TXT_COLOR = "#000000"

shapes = []          # EasyEDA shape strings
pins = []            # (refdes, pinnum, x, y)
netlabels = []       # (name, x, y)
wires = []           # list of point lists [(x, y), ...]


# --------------------------------------------------------------------------
# Variants.  Only the frequency-setting network differs: the pot gang in series
# with rs sets R, and c is the integrator capacitor, so f = 1 / (2*pi*R*C) with
# R sweeping from rs to rs + 20k.  Q, topology and every other value are shared.
# --------------------------------------------------------------------------
DUAL_ICS = {
    # role:   (refdes, top pin, bottom pin, out pin, power pins)
    "buf":  ("U1A", (3, "+"), (2, "-"), 1, (8, 4)),
    "sum1": ("U1B", (6, "-"), (5, "+"), 7, None),
    "int1": ("U2A", (2, "-"), (3, "+"), 1, (8, 4)),
    "int2": ("U2B", (6, "-"), (5, "+"), 7, None),
    "sum2": ("U3A", (2, "-"), (3, "+"), 1, (8, 4)),
    "int3": ("U3B", (6, "-"), (5, "+"), 7, None),
    "int4": ("U4A", (2, "-"), (3, "+"), 1, (8, 4)),
    "inv":  ("U4B", (6, "-"), (5, "+"), 7, None),
}

# Standard 14-pin quad pinout (TL074 / MC33079 / OPA4134 / LME49740):
#   A out 1, -in 2, +in 3 | V+ 4 | B +in 5, -in 6, out 7
#   C out 8, -in 9, +in 10 | V- 11 | D +in 12, -in 13, out 14
# Filter 1 fills U1 exactly; filter 2 fills U2 exactly.
QUAD_ICS = {
    "buf":  ("U1A", (3, "+"), (2, "-"), 1, (4, 11)),
    "sum1": ("U1B", (6, "-"), (5, "+"), 7, None),
    "int1": ("U1C", (9, "-"), (10, "+"), 8, None),
    "int2": ("U1D", (13, "-"), (12, "+"), 14, None),
    "sum2": ("U2A", (2, "-"), (3, "+"), 1, (4, 11)),
    "int3": ("U2B", (6, "-"), (5, "+"), 7, None),
    "int4": ("U2C", (9, "-"), (10, "+"), 8, None),
    "inv":  ("U2D", (13, "-"), (12, "+"), 14, None),
    # A third quad, fitted only where output_buffers is on: one unity-gain
    # follower per band between that band's volume pot and its terminal
    # block.  The supply pins are put on the SPARE section rather than on
    # section A as elsewhere - the +15V/-15V labels amp() draws reach 76 px
    # below the centreline, which lands on the next row's designator when
    # the three buffers are stacked on a 110 px pitch.  The spare has a
    # row to itself and the room for them.
    "obufH": ("U3A", (3, "+"), (2, "-"), 1, None),
    "obufM": ("U3B", (5, "+"), (6, "-"), 7, None),
    "obufL": ("U3C", (10, "+"), (9, "-"), 8, None),
    "ospare": ("U3D", (12, "+"), (13, "-"), 14, (4, 11)),
}

PIN_ROLE = {}      # (refdes, pin) -> "role.function", for cross-variant checks

# Buffered outputs.  Without them the source impedance at each terminal
# block is the volume pot's wiper - up to a quarter of the pot's track, so
# 2.5 kohm at the worst setting on a 10k pot - and the amplifier's input
# impedance sits across the lower half of that track, so it both loses
# level and bends the taper by an amount that depends on which amplifier is
# plugged in.  That is tolerable for a crossover fed from a preamp and
# wrong for something used AS a preamp.  A unity-gain follower per band
# makes the output impedance the op-amp's, which is milliohms.
_OBUF = os.environ.get("OUTPUT_BUFFERS", "1") != "0"

# Per-output muting, and the power-up mute that comes with it.
#
# The switch carries no audio.  A JFET shunts each buffer's input to
# ground through a series resistor, and the front-panel button only pulls
# that JFET's gate - so there is nothing to click, and no signal wiring
# running out to the panel and back.  The JFET is a DEPLETION device: it
# conducts at Vgs = 0, which means every output is muted from the moment
# the board has power, and stays muted until the soft-start RC has pulled
# the gates to the negative rail.  Turn-on muting is therefore not a
# separate circuit, it is the resting state of the parts already fitted.
_MUTE = os.environ.get("MUTE", "1") != "0"

# Which of the button's two throws carries GND.  See switch_dpdt().
# "alpha" (default) is the end AWAY from the plunger, on the reading
# that a push-lock latches its common onto the far contacts; set
# MUTE_SW_SENSE=beta if the built board mutes when the button is OUT.
_MUTE_SW_ALPHA = os.environ.get("MUTE_SW_SENSE", "alpha") != "beta"

# Panel mute indicators.  With them ON, the button's second pole switches
# a current-limited LED feed out to J6 (lit = that band is playing) and
# R37-R39 set the current.  With them OFF, R37-R39 and J6 come off the
# board entirely and the second pole is wired in PARALLEL with the first
# instead, which is not a consolation prize: it halves the mute contact
# resistance and gives the one dry-circuit contact on the board a second
# path.  The cost of ON is three more parts and six more nets in the panel
# row, which is the most congested strip on this board.
_MUTE_LEDS = os.environ.get("MUTE_LEDS", "1") != "0"
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

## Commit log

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2026-08-16 Retune filter 2 to 71-180 Hz; reframe the guidance around separation
    Filter 2 becomes R17/R18 = 13k with C3/C4 = 68nF, giving 70.9 - 180.0 Hz, so
    the two tuning ranges no longer overlap (filter 1 starts at 195 Hz). Filter 1
    is unchanged at 4.7k / 33nF.
    Removing the overlap is worth doing but does not do what it appears to. Ranges
    that merely abut still meet at the boundary, so the worst-case setting only
    improves from 0.76:1 (-5.17 dB) to 1.08:1 (-3.57 dB). The stock ESP values have
    the same exposure at 1.42:1 (-2.62 dB) - nothing in this topology enforces
    separation, because the two filters are tuned independently. The docs and the
    range diagram now say so directly: the diagram marks e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
    [bom-retuned.csv]
2026-08-16 Use 11k Q resistor in the retuned variant; document where accuracy pays
    R3/R13 become a per-variant value. The stock variant keeps the published 12k
    (Q = 0.489); the retuned variant uses 11k, a stock E12 value giving Q = 0.503,
    which cuts the worst summed-response error from -0.20 dB to +0.05 dB at no cost.
    The ESP article makes the same suggestion.
    Also documents the improvements available without changing the circuit: what to
    match and what not to bother matching (a mismatch within a filter moves f0 and Q
    by its square root, so 20% costs 0.79 dB), why pot tracking outranks op-amp
    choice, why log-taper pots are a bad trade here, and that the section count
    splits perfectly four-and-four at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
    [bom-retuned.csv, bom.csv]
2026-08-16 Add quad op-amp variant: two 14-pin quads instead of four duals
    The eight op-amp sections split four-and-four exactly on the filter boundary,
    so filter 1 fills U1 and filter 2 fills U2. Halves the IC count and the bypass
    caps (8 -> 4), and keeps each filter's inter-section crosstalk inside its own
    package, where the sections are already coupled by design. Drawn with the
    MC33079; any standard quad pinout drops in.
    Op-amp placement is now driven by a role -> (refdes, pins, power) map per
    variant rather than hardcoded designators, so the dual and quad packagings
    share one layout. The cross-variant check was tightened accordingly: it now
    compares signal connectivity with op-amp pins named by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
    [bom-retuned-200hz-1khz.csv, bom-retuned-quad.csv]
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2026-08-16 Add routed SMD board for JLCPCB fabrication and assembly
    Adds an SMD variant of the schematic and tools/gen_pcb_smd.py, which places SMD
    footprints matching real LCSC parts, routes every net with a two-layer grid maze
    router, and verifies the result. 81.3 x 61.0 mm, 46 footprints, 121 pads, 109
    tracks, 38 vias, fully routed.
    Verification does not reuse the router's own bookkeeping: exact pairwise
    geometric clearance between every copper feature sharing a layer, union-find
    connectivity per net with vias linking layers, mounting-hole keepout, and
    pad-set equality with the schematic in both directions. This caught four
    defects that would otherwise have reached the fab:
    - vias placed too c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
    [bom-retuned-quad-smd.csv, jlcpcb-bom-retuned-quad-smd.csv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]
2026-08-16 Mount the frequency pots on the board; rework layout and routing
    VR1 and VR2 become board-mounted 9mm dual-gang pots on the front edge, 25mm
    apart for knob clearance, with the sockets moved to the opposite edge so a boxed
    unit wires up sensibly. The pot footprint is the standard six-terminal
    two-row pattern on 0.2in centres with non-plated holes for the locating bosses;
    LCSC stocks RK09-family 20k parts but the API exposes neither gang count nor
    mechanical dimensions, so this is drawn from the standard pattern and is flagged
    in the docs as needing a datasheet check.
    Getting this routed took four fixes, each found by the verifier rather than by
    inspection:
    - the pot locating holes were n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
    [jlcpcb-cpl-retuned-quad-smd.csv]
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2026-08-16 Shrink the SMD board to the smallest size that still verifies
    Board size and slot pitch become environment overrides, so the generator can be
    swept rather than sized by guesswork. Sweeping down from 340x280 units, the
    smallest that routes and passes every check is 320x260 - 81.3 x 66.0 mm, 13%
    less area than before, and now smaller than the wired-pot board was despite
    carrying two board-mounted pots. 310x250 and below leave nets unroutable.
    Worth recording why it does not go further: components occupy only about 13% of
    the board. The apparently empty space is routing headroom. On two layers, at
    8 mil track and clearance, with SOIC pads that can only break out sideways, the
    router sets t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
    [jlcpcb-cpl-retuned-quad-smd.csv]
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2026-08-16 Adopt the side-by-side quad layout on a 2.5mm taller board
    Sweeping the side-by-side arrangement against board height: 320x270, 320x280 and
    320x290 all route and verify, so 270 units is the smallest tried - 81.3 x 68.6 mm,
    against 81.3 x 66.0 mm stacked. Ten units of height is what the ground pin that
    failed at 320x260 needed.
    The extra 2.5mm buys a better board, not just a working one: each filter now has
    its own half with its frequency pot directly below, and it routes with 50 vias
    instead of 57 and a shorter ratsnest (867mm against 914mm). Fewer vias on a
    signal board is worth having in its own right.
    Both arrangements stay available - IC_LAYOUT=stacked selects the old one -
    alongside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
    [jlcpcb-cpl-retuned-quad-smd.csv]
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2026-08-16 Use the board beside and between the pots: 76.2 x 44.4 mm
    The slot grid stopped 75 units above the bottom edge, so the strips either side
    of the potentiometers and the gap between them were never offered to the
    placer - dead board that the pots did not actually occupy. Letting slots run to
    the bottom edge takes 27% off the height, 61.0mm to 44.4mm, at the same width.
    The pot courtyards are already in fixed_boxes so their own footprints are still
    excluded; the mounting holes are now added there too, since two of them sit in
    that band.
    Sweeping height at 300 units wide: 175 routes, 165 and below do not.
    side by side, unrotated 81.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
    [jlcpcb-cpl-retuned-quad-smd.csv]
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2026-08-17 Trace widths matched to purpose; enforce no silk over copper
    Every trace used to be a uniform 8 mil regardless of what it carried. Signal
    traces are now 10 mil; +15V, -15V and GND (combined op-amp supply current, and
    for GND the audio return path) are 16 mil - visibly a rail rather than a
    signal line, and comfortably wider for real supply current and lower
    resistance/inductance.
    Getting there correctly, not just wider, took two real fixes:
    - Pad keepouts were sized from the pad's OWN net, which is backwards - a
    pad's clearance requirement is about what might route PAST it, not what
    net the pad itself is on. This under-reserved every signal pad by exactly
    the signal/power widt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
    [jlcpcb-cpl-retuned-quad-smd.csv]
2026-08-17 SMD board: courtyard-aware placement, per-part rotation, chamfered corners, wider/proportional traces
    Fixes a real pre-existing defect: two adjacent 1210 caps overlapped by
    0.6 units even before any of this round's changes, because nothing
    before now checked component *bodies* against each other, only copper.
    Caught by adding a footprint-courtyard-overlap DRC check, then fixed by
    making placement collision-aware by construction (checks real per-part
    boxes during both initial assignment and the local-search loop) instead
    of just widening the slot pitch for every part.
    Placement search now also tries each 0805 part's own rotation (not just
    position), gated the same way position swaps are: a r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
    [jlcpcb-cpl-retuned-quad-smd.csv]
2026-08-17 Add per-output volume control (SMD build): three audio-taper pots, plus router fixes needed to fit them
    Each output (HIGH/MID/LOW) gets its own single-gang 10k audio-taper pot
    (Alps RK097111080R, LCSC C470577 - a real, stocked part with a verified
    EasyEDA footprint, sourced by tracing the user's AliExpress "RK097N" link
    back to the genuine Alps series it rebrands) wired as an attenuator
    between that band's filter output and its terminal block. Panel layout,
    left to right: HIGH VOL, HIGH/MID freq, MID VOL, MID/LOW freq, LOW VOL -
    five controls on a uniform 80-unit pitch, since front-panel volume was
    specifically requested (this board doubles as the user's preamp).
    Schematic: the filter outpu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
    [bom-retuned-quad-smd.csv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]
2026-08-17 Reverse volume-pot panel order, use real RK097 pad geometry, fix long-net routing bug
    Panel order flipped per request: LOW - MID/LOW freq - MID - HIGH/MID freq -
    HIGH, left to right (was HIGH...LOW). Only the position formulas for
    VR1/VR2/VR3/VR5 change; ref-to-net wiring is untouched.
    Pulled the real LCSC/EasyEDA PCB footprint for C470577 (the RK097 part
    chosen for these pots) instead of continuing to reuse the dual-gang
    footprint's pitch as a stand-in: real pin pitch is 2.5mm, not the 5.08mm
    carried over from VR1/VR2 - the previous footprint was about 2x too wide,
    which is why a rendered preview of it looked barely different from the
    dual-gang pots. fp_pot_single() now draws pads on the r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
    [jlcpcb-cpl-retuned-quad-smd.csv]
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2026-08-17 Ground stitching vias, larger human-read labels, real pot body geometry, faster sweeps
    Ground stitching: R1, R3 and R13 are the only ground connections with no
    through-hole part nearby to tie the two ground pours together, so each now
    gets a deliberate via placed beside it after routing finishes. Most
    valuable at R1, the input stage's ground reference. Each candidate is
    checked with the router's own strict via_ok(), so a position that would
    crowd real copper is skipped rather than forced (5 GND vias placed).
    Label sizes: introduces LABEL_SIZE (1.27mm) for everything a person
    actually reads while wiring the board or setting a knob - connector pin
    names, J/TP/U/VR designators, pot function la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
    [jlcpcb-cpl-retuned-quad-smd.csv]
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2026-08-18 Layout-first board that verifies clean: 97.8 x 60.7 mm, chosen by routing candidates
    Replaces the hand-placed board with one the placement search produced. It
    verifies clean: all nets connected, all clearances >= 8 mil, no unrouted
    nets, pads match the schematic exactly.
    The honest comparison is that it is the SAME AREA as the board it replaces
    (5936 mm2 vs 5964) - 8.9 mm narrower, 4.8 mm taller. The gain is method,
    not millimetres: nothing has a hand-tuned coordinate, rotation is searched
    for every part rather than two, the width falls out of the panel row's own
    geometry instead of being a number that happened to route, and a candidate
    can now be verified in under a minute.
    tools/find_boa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
    [jlcpcb-cpl-retuned-quad-smd.csv]
2026-08-18 Validate for EasyEDA import and fabrication; cut run time 25 min -> 4.5 s
    Adds tools/validate_fab.py, which checks the two ways a board fails after
    it leaves the generator and that verify() says nothing about: EasyEDA
    silently mangling a malformed shape, and the fab being unable to make a
    feature that is geometrically perfect. It re-reads the written artifacts
    rather than trusting the generator, same principle as verify().
    Two real defects it found, neither visible to any geometric check:
    * Every silkscreen line on the board was too thin to print - 0.127 mm for
    body outlines and 0.102 mm for terminal wire-entry marks, against
    JLCPCB's 0.15 mm minimum. SILK_W is now 0.178 mm. Not free: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
    [jlcpcb-cpl-retuned-quad-smd.csv]
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2026-08-18 Fix the decoupling defect: bypass caps now 4.2-10.0 mm from their op-amp pins
    Was 37-63 mm, which is no decoupling at all. The placement search cannot
    see this on its own - a bypass cap sits on +15V/-15V and GND, nets that
    already span the board, so its wirelength barely changes wherever it goes -
    so it is now told explicitly, via a pin-to-pin proximity term.
    The constraint itself was written last round and switched off, because with
    it on nothing routed across 208 seed/route-order combinations. That was a
    budget problem wearing an engineering problem's clothes: each attempt cost
    ~30 s, nearly all of it Python placement, so 208 was as far as it went.
    With the anneal compiled a trial costs ~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
    [jlcpcb-cpl-retuned-quad-smd.csv]
2026-08-18 Circuit fixes from the design review: written, measured, and gated off
    Output DC blocking (OUTPUT_CAPS=1) and bulk supply decoupling
    (BULK_CAPS=1) are now in gen_schematic.py, with the invariant checks taught
    about them rather than worked around: check_power counts bulk caps, and
    signal_map now names the supply refs explicitly instead of excluding "C5
    and up" by regex - that regex would have silently swallowed the new SIGNAL
    caps too, quietly weakening the one check that guarantees the variants
    agree.
    Both are off by default because the board will not route with them.
    Measured, after fixing the determinism bug below:
    49 footprints (as shipped) 1 clean in 80
    52 (+ output bloc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
    [gen_schematic.py]
2026-08-19 Make ground a plane, and ship the two circuit fixes it was blocking
    Output DC blocking (C11-C13) and bulk supply decoupling (C9/C10) were
    written months ago, correct, and switched off, because the board would
    not route with them: 52 footprints was 0 clean in 320 seed/route-order
    combinations and 54 was 0 in 320, and shrinking the added parts to a
    third of their area changed nothing (0 in 160). Both are now on by
    default on a board that verifies clean.
    What was actually in the way was not the router and not the board size.
    The board has always carried a GND pour on both layers, but nothing
    verified it, so ground was ALSO drawn as an ordinary net - the largest
    net on the board, and route_orde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
    [bom-retuned-quad-smd.csv, jlcpcb-bom-retuned-quad-smd.csv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]
2026-08-19 Preamp-readiness, circuit side: 47k input, buffered outputs, bleeders
    Three changes so the board can be used AS a preamp rather than only
    between one and the power amps.
    R1: 10k -> 47k. R1 is the input impedance - it is the bias return for
    U1A's non-inverting input and C0 blocks DC, so nothing else sets what
    the source sees. 10k is a power-amp figure: it loads a passive volume
    control or a valve output stage hard enough to lose level and bass, and
    it is the reason docs/design-review.md section 4 had to say an external
    master volume would not work properly. 47k is the ordinary line-level
    value and fixes that. The cost is bias-current offset - 300 nA through
    47k is 14 mV at the buffer output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
    [bom-retuned-200hz-1khz.csv, bom-retuned-quad-smd.csv, bom-retuned-quad.csv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]
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2026-08-19 Rip-up and reroute: learn the route order from what actually failed
    The measurement that explains years of this project's routing trouble: an
    SOIC-14's pads are 2.5 units apart edge to edge, and a 12 mil trace needs
    1.2 + 2 x 0.8 = 2.8 units to pass between two of them. It does not fit.
    Every pin on every IC has to escape OUTWARD along a channel it shares with
    its neighbours, so whichever net is routed first takes the channel and the
    rest are locked out - not for want of board area, not for want of a better
    placement, but because single-pass routing meets a pitch that does not
    admit a second trace. That is why route_order() had grown three separate
    hand-reasoned special cases, and why adding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
    [gen_schematic.py]
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2026-08-19 Commit the clean 63-footprint board: 97.5 x 82.8 mm, SEED=18
    pcb/ matches the netlist again for the first time in several commits.
    board 97.5 x 82.8 mm | 63 footprints | 172 pads | 247 tracks | 141 vias
    utilisation 61%
    verified: all nets connected, all clearances >= 8 mil, no unrouted
    nets, pads match the schematic exactly
    validate_fab.py --online: OK
    The board carries everything the preamp round added: 47k input impedance,
    per-band output buffers on U3 with their build-out resistors, output
    bleeders, output DC blocking and bulk supply decoupling.
    For scale: this part count was 0 clean in 96 attempts before the router
    and placement work. The first search afte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
    [jlcpcb-bom-retuned-quad-smd.csv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]
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2026-08-19 Pin each mute shunt to the buffer it mutes
    A JFET left free ends up wherever the surrogate likes, which for a part
    whose only job is to short one specific pin is anywhere at all: its drain
    IS the node it mutes, so a distant shunt picks up everything its trace
    runs past, and its gate line has to be dragged back across the board to
    the panel header. The first 82-footprint attempt failed with 5 unrouted
    and 2 split, among them MG2 (a gate) and LOW_VOL - the scattered-shunt
    signature.
    MUTE_NEAR holds each Q within 40 units of its own buffer's input pin,
    using the same mechanism, and for the same reason, as BYPASS_NEAR: the
    constraint is local and physical and nothing else in the cost model can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
    [gen_schematic.py]
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2026-08-19 Add the master volume, and the mute chain's missing part numbers
    MASTER VOLUME (VR6, one new footprint)
    It goes at the INPUT, ahead of the buffer, for two reasons: it then sets
    the board's input impedance itself so R1 stops having to, and attenuating
    before any gain stage stops a hot source clipping the filter rather than
    merely turning down something already clipped.
    The cost is ~2 dB of insertion loss at mid-rotation, where the wiper's
    source impedance is highest and works against R1. Putting it after the
    buffer would avoid that, but the pot would then drive R2 directly and its
    wiper impedance would sit in series with the summing resistor - which
    changes the FILTER's gain with the volume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
    [bom-retuned-quad-smd.csv, jlcpcb-bom-retuned-quad-smd.csv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]
2026-08-19 Commit the complete board: mute, soft start and master volume, verified
    board 114.3 x 102.9 mm | 83 footprints | 222 pads | 213 tracks | 130 vias
    utilisation 51%
    pcb/ matches the netlist. Everything asked for in this round is on it:
    master volume, per-band volume, 47k line input, buffered outputs with
    build-out resistors, DC blocking and bleeders, bulk and per-IC decoupling,
    and per-output muting with power-up soft start.
    Two findings worth keeping, both about how to search rather than what to
    build:
    WIDTH IS NOW SET BY THE PA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
    [jlcpcb-bom-retuned-quad-smd.csv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]
2026-08-19 Price plane-pad via room in the placer; screen seeds before routing them
    Adds a placement term for the one statement the escape term cannot make:
    a pad on a POURED net needs somewhere a via will fit. Escape is capped on
    pad count, so a SOIC face asks for four track pitches and scores the same
    whether the gap in front of it is three units or nine - and three fits no
    via, while the channel between two of its own pads is 2.5 units, narrower
    than a track plus its clearances. PLANE_GAP is therefore not tuned: it is
    VIA_PAD + 2*CLEAR = 4.4 units. The term shares escape_of()'s neighbour
    scan, so it costs four multiplications rather than a second pass, and is
    mirrored in anneal.c.
    It was built a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
    [gen_schematic.py]
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2026-08-20 The committed board is now 114.3 x 77.5 mm, verified clean
    SEED=4 ROUTE_SEED=0 at the new W_H, regenerated with artifacts:
    board 114.3 x 77.5 mm | 83 footprints | 222 pads | 233 tracks | 151 vias
    board utilisation 60%; largest empty rectangle 24 x 29 mm at (0, 14)
    against 114.3 x 102.9 mm, 213 tracks, 130 vias and 51% utilisation for the
    board it replaces - a quarter less board for the same circuit. No DRC
    problems, and validate_fab.py --online passes: imports as an EasyEDA PCB
    and every dimension is inside JLCPCB's standard 2-layer capability.
    This is the first board to verify clean since the plane-escape placer term
    went in, which had left the repo carrying a pre-term layout that n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
    [jlcpcb-cpl-retuned-quad-smd.csv]
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2026-08-20 Generate real subcircuit diagrams; the old ones were broken or misleading
    Three problems with the subcircuit docs:
    * Both "-hi-crop" SVGs were broken images. They pointed at
    ../../schematic/... from docs/subcircuits/images/, which resolves to
    docs/schematic/ - one level short. Fixing the path would not have
    helped: they work by nesting an <image href> to another SVG, which
    GitHub does not render, so they could never have displayed.
    * mute.svg and level-pots.svg were hand-drawn boxes with part names typed
    into them, in nothing like the schematic's style, and the mute one
    captioned J6 "Input" - J6 is the panel header. A wrong diagram that
    looks like a diagram is worse than no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
    [gen_schematic.py]
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2026-08-20 The 4-layer board verifies CLEAN: 141.7 x 70.4 mm, 0 DRC problems
    SEED=35 ROUTE_SEED=15, now the defaults so a bare `python3
    tools/gen_pcb_smd.py` rebuilds the committed artifacts. 86 footprints,
    242 pads, 262 tracks, 166 vias, utilisation 58%. verify() passes every
    check - pairwise clearance, union-find connectivity, mounting-hole
    keepout, board-edge clearance, schematic-pin agreement, silk over copper,
    courtyard overlap, ground-pour reachability - and validate_fab.py passes
    offline.
    Smaller than the two-layer attempt as well: 141.7 x 70.4 against
    146.3 x 74.7.
    How it was found, because the shape of the search is the lesson:
    2 layers, ~115 seeds + route sweeps 10 (floo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
    [jlcpcb-cpl-retuned-quad-smd.csv]
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2026-08-20 Lay header pin names out in board space, and find a board 17% smaller
    Two changes, the second made possible by the first.
    **The J6 pin names folded back over its own pads at rot 90.** fp_hdr()
    put each label at a fixed offset above its pad in the LOCAL frame, which
    is clear at rot 0 and lands on J6.1-J6.3 once the anchor turns with the
    part and the glyphs do not. This is the bug silk_ref_beside() was written
    for, still live in the plain labels because only the designator was ever
    given the board-space treatment. silk_beside() now exists and shares
    _beside() with it.
    The more useful half is where the check moved. verify() inspects the
    board that got built, so it only saw the angles that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
    [jlcpcb-cpl-retuned-quad-smd.csv]
2026-08-20 Round 1: replace a dead LCSC part, fail on unorderable parts, drop dead scripts
    **The 10uF was unorderable.** C46550416 covered seven designators (C0,
    C11-C16) and an LCSC keyword search returns ZERO results for it - not a
    zero-stock hit, which is what an end-of-lifed number looks like. The
    board could not be assembled as specified while every geometric check
    passed, because nothing about the copper was wrong. Replaced with
    C2858858 (KNSCHA 10uF 50V, SMD D5xL5.4mm, 50240 in stock) - same package,
    so no footprint or layout change, and 50 V is 3.3x the rail it sits
    across. Every BOM line now resolves against live LCSC data.
    **validate_fab.py now FAILS on a part it cannot find**, where it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
    [jlcpcb-bom-retuned-quad-smd.csv]
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
